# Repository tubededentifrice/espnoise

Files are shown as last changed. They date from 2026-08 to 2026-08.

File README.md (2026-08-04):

# ESPNoise

ESPNoise is a privacy-first noise warning sign for shared workspaces. An ESP32
measures sound energy and lights the word **NOISE** only when the room stays
loud. Short sounds, such as a cough or a dropped object, do not start the
alarm by themselves.

<p align="center">
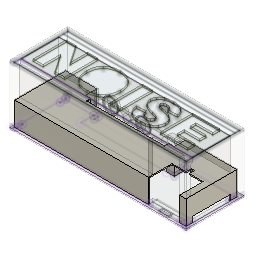
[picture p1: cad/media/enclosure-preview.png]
ESPNoise production enclosure assembly
  
</p>

The repository includes the production enclosure, hardware design, PlatformIO
firmware, and an optional iPhone settings app.

## Main features

- Sustained-noise detection with a rolling decision window
- Green, orange, and red warning levels
- Ten SK6812 RGB plus warm-white pixels behind a printed diffuser
- Optional passive buzzer with a hard power switch
- A 30-minute mute button
- No raw microphone recording or storage
- Wi-Fi off; Bluetooth Low Energy is used only for the optional app
- Firmware targets for a full-size ESP32 and a LOLIN32 Lite

## Production build

The production build uses a full-size ESP32 board and a separate, power-only
USB-C input. A regulated 5 V supply powers the controller and peripherals. The
ESP32 USB-C port stays inside the enclosure as a firmware-service port. No
battery is necessary.

| Item | Production specification |
| --- | --- |
| Controller | Full-size ESP32 development board with USB-C |
| Microphone | ICS-43434 digital I2S microphone on the carrier PCB |
| Display | 10 SK6812 RGB plus warm-white, 32-bit pixels |
| Data buffer | SN74AHCT125PWR, 3.3 V input to 5 V output |
| Sound | 5 V passive electromagnetic buzzer and MMBT3904 driver |
| Controls | Momentary mute button and maintained hard buzzer switch |
| Power | Regulated 5 V, 2 A minimum; 3 A recommended |
| Enclosure | 164 mm × 54 mm × 54.5 mm main case envelope |

See the [bill of materials](docs/bom.md) for the complete part specification.

## 3D-print files

The ready-to-print package and editable source are in
[`cad/production`](cad/production). Start with one of these files:

- [`espnoise.3mf`](cad/production/espnoise.3mf) contains four arranged plates
  and the saved Bambu Studio print profile.
- [`espnoise.f3d`](cad/production/espnoise.f3d) is the editable Autodesk Fusion
  design.
- The individual STL files support other slicers and printers.

The package contains the case, back, reflector, illuminated letters, optional
letter mould, mute-button cap, and buzzer-switch cap.

| Reflector and switch cap | Case, back, and button cap | Letters | Letter mould |
| :---: | :---: | :---: | :---: |
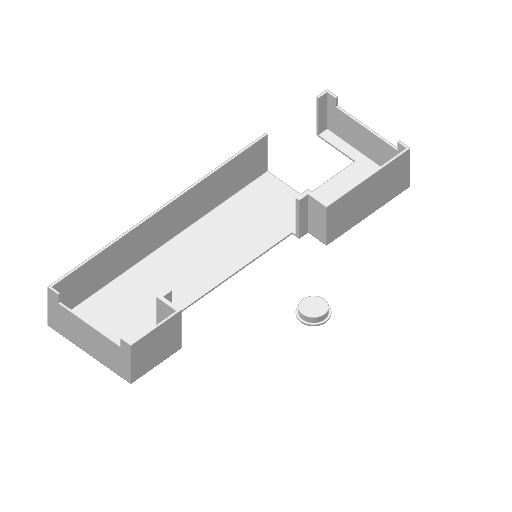
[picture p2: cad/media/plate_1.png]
Reflector print plate
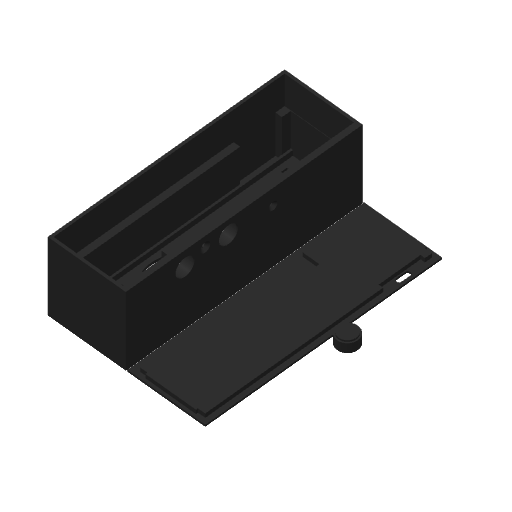
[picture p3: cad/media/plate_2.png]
Case print plate
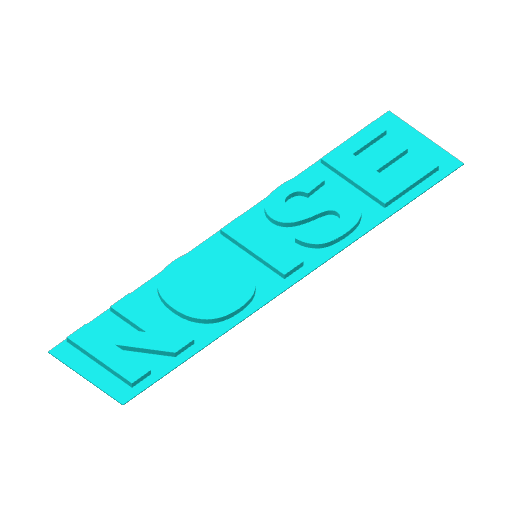
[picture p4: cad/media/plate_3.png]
Letter print plate
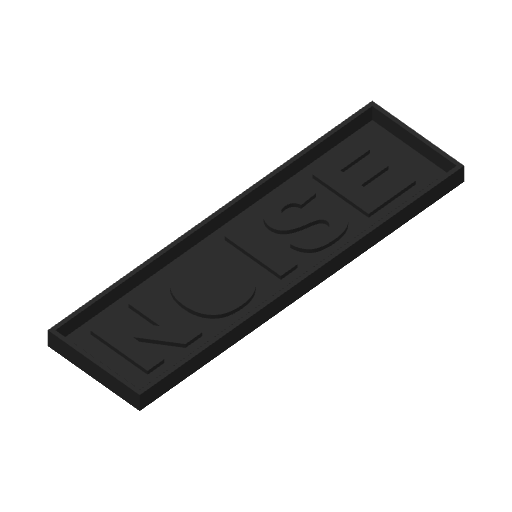
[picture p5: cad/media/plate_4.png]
Letter mould print plate
|  |  |  |  |

The saved profile uses a 0.4 mm nozzle, 0.2 mm layers, two wall loops, 15%
infill, and no supports. Check the profile for your printer and material before
you print. See the [enclosure guide](cad/README.md) for file dimensions,
materials, and assembly notes.

## Wiring

The production wiring uses one common ground. The LED supply does not pass
through the ESP32 board.

```mermaid
flowchart LR
  USB["External power-only USB-C<br>5 V"] --> SPLIT["5 V and GND split"]
  SPLIT --> ESP["ESP32<br>5V/VIN and GND"]
  SPLIT --> FUSE["0.5 A hold fuse"]
  FUSE --> RAIL["5 V peripheral rail"]

  ESP -->|"3V3, GND<br>GPIO26 SCK<br>GPIO25 WS<br>GPIO32 SD"| MIC["ICS-43434<br>L/R to GND"]
  ESP -->|"GPIO18"| AHCT["SN74AHCT125PWR<br>5 V supply"]
  AHCT -->|"330 ohm"| LED["10 × SK6812 RGBW<br>5 V at both ends"]
  RAIL --> AHCT
  RAIL --> LED

  ESP -->|"GPIO23 PWM<br>through 1 kohm"| Q1["MMBT3904 driver"]
  RAIL --> SW["Hard buzzer<br>power switch"]
  SW --> BUZ["Passive magnetic buzzer"]
  BUZ --> Q1

  BTN["Mute button<br>GPIO27 to GND"] --> ESP
```

| Function | ESP32 pin |
| --- | ---: |
| ICS-43434 clock | GPIO26 |
| ICS-43434 word select | GPIO25 |
| ICS-43434 data | GPIO32 |
| SK6812 data through SN74AHCT125PWR | GPIO18 |
| Buzzer PWM through 1 kohm and MMBT3904 | GPIO23 |
| Mute button to GND | GPIO27 |
| Optional battery-boost enable | GPIO13 |

Keep the buzzer switch in the buzzer 5 V wire. Software must not override this
switch. Keep the external two-wire USB-C input separate from the ESP32
firmware-service port. If the power input exposes CC1 and CC2, connect one
5.1 kohm pull-down from each CC pin to GND. Do not connect CC1 to CC2.

See the [complete wiring guide](docs/wiring.md) and the
[interactive prototype-board diagram](docs/prototype-board-wiring.html) before
assembly.

## How detection works

The default rule listens for one second in each ten-second period. It stores
only the maximum sound level from each observation. At least three of the last
six observations must cross a threshold before the alarm starts. Two quiet
checks clear an active alarm.

The default thresholds are in dBFS until you calibrate the unit against a sound
level meter. They are not certified dBA values. Detector values and thresholds
are in [`firmware/include/config.h`](firmware/include/config.h).

## Build guide

1. Check the [bill of materials](docs/bom.md).
2. Print and prepare the [production enclosure](cad/README.md).
3. Follow the [modular assembly stages](docs/modular-build.md).
4. Make the connections in the [wiring guide](docs/wiring.md).
5. Build and upload the [firmware](firmware/README.md).
6. Use the [test and adjustment procedure](docs/detection.md).
7. If necessary, install and configure the optional iPhone app as described in
   [the app and Bluetooth guide](docs/app-and-bluetooth.md).

## Safety and privacy

- Start a new or changed build at 25% LED brightness or less. The production
  USB profile uses its higher limit only after the documented power test.
- Disconnect external 5 V power before you connect the ESP32 service USB port.
- Do not connect a battery to the full-size ESP32 board.
- For the optional battery build, use one protected 3.7 V LiPo pack with the
  correct plug polarity. Do not use loose lithium cells.
- Do not cover the microphone acoustic hole.
- The firmware processes sound levels in memory and does not save raw audio.

## Repository map

```text
cad/                 Production 3D-print files and editable CAD source
docs/                Hardware, wiring, assembly, and test guides
firmware/            PlatformIO firmware for both ESP32 controller options
ios/                 Optional iPhone companion app and Xcode project
```

## License

This project uses the [Functional Source License 1.1, ALv2 Future
License](LICENSE.md). Each release changes to the Apache License 2.0 two years
after that release first becomes available.

FSL is a source-available license before the change date. It permits study,
modification, redistribution, and most uses, but it limits competing commercial
products and services until the change date.

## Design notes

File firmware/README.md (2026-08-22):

# Firmware

## Requirements

- `uv` 0.12 or later, or the PlatformIO IDE extension
- A USB data cable
- The `esp32dev` board definition for the full-size USB-C board
- The `lolin32_lite` board definition for the WEMOS battery board

The repository accepts a third-party dependency only after it is two weeks
old. Reviewed commits from `opendle/opendle-esp32` and
`opendle/opendle-electronics` do not use this cooldown. All dependencies still
need exact versions, hashes, or full Git commits. Git tags and version ranges
are not permitted.

Run the fail-closed policy check before an install or dependency update. The
check verifies the `uv.lock` hashes and dates against PyPI. It reads PlatformIO
and Git commit dates from their services. It also rejects a missing hash, a
version range, a Git tag, or a short Git commit.

```sh
uv sync --locked
uv run --locked opendle-deps check
```

Use `opendle-pio` for each PlatformIO command. The shared tool runs the same
policy check before PlatformIO can install a package.

The same check runs in GitHub Actions. Protect `main` and require the
`Dependency age / check` result so that a change cannot bypass the check. An
urgent security fix that is less than two weeks old needs an explicit policy
change and review. Do not silently remove the cooldown.

## Build

From the repository root, run:

```sh
uv run --locked opendle-pio run
```

This command builds the first USB-powered board. Its ten-pixel power test
passed, so this profile uses 100% LED brightness. The battery board stays an
optional environment and keeps the 25% limit. Build it only when you start the
battery stage:

```sh
uv run --locked opendle-pio run --environment esp32dev
uv run --locked opendle-pio run --environment lolin32_lite
```

At each USB production startup, all ten pixels show green, orange, and red in
quick succession. The buzzer plays one short rising note with each color. The
check takes less than half a second. The detector starts after it finishes.
The hard buzzer switch can disable the notes without disabling the light check.

Use the temporary LED-test environment to show red, green, blue, and
warm-white for one second each after startup:

```sh
uv run --locked opendle-pio run --environment esp32dev_led_test --target upload
```

For a one-pixel bench test, use the fast profile. It listens for 3 seconds in
each 5-second period, keeps a 15-second history, requires at least 50% of the
saved maxima, and uses full LED brightness. It also plays a short buzzer chime
after the LED test:

```sh
uv run --locked opendle-pio run --environment esp32dev_fast_test --target upload
```

Use the calibration profile with the assembled USB-powered product. Send `g`,
`o`, or `r` over the serial monitor. The strip shows the selected solid color
while the firmware measures one 10-second sample. The result is the median of
ten one-second maxima. The buzzer stays off. The calibration profile does not
save raw microphone audio.

```sh
uv run --locked opendle-pio run --environment esp32dev_calibration --target upload
uv run --locked opendle-pio device monitor --baud 115200
```

The tested passive piezo buzzer uses a 2N3904 low-side driver. GPIO23 connects
to its base through 1 kohm. The firmware drives it with 2.4 kHz PWM. The
hard switch stays in the buzzer 5 V wire.

The runtime buzzer-volume value sets the electrical tone amplitude. The
firmware maps this value to the PWM waveform for the passive piezo. Acoustic
loudness is not linear and depends on the buzzer and its enclosure, so adjust
the value after the case is assembled.

## Firmware modules

| Module | Files | Responsibility |
| --- | --- | --- |
| Board profile | `include/board_profile.h` | GPIO pins and optional switched power |
| User settings | `include/config.h` | K, N, X, threshold, colors, and timing |
| Audio input | `include/audio_input.h`, `src/audio_input.cpp` | INMP441 and dBFS frames |
| Detector | `include/noise_detector.h`, `src/noise_detector.cpp` | Observation maximum, rolling history, and X decision |
| Alarm output | `include/alarm_output.h`, `src/alarm_output.cpp` | SK6812, buzzer, and optional power switch |
| Mute control | `include/mute_button.h`, `src/mute_button.cpp`, `include/mute_state.h`, `src/mute_state.cpp` | Button filtering, mute timer, double-press control, and Bluetooth hold detection |
| BLE service | `include/ble_service.h`, `src/ble_service.cpp` | Encrypted settings writes, readback, and status |
| Settings packet | `include/config_packet.h`, `src/config_packet.cpp` | 32-byte packet, limits, and fingerprint |
| Device name | `include/device_name.h`, `src/device_name.cpp` | 20-byte UTF-8 name packet and validation |
| Settings storage | `include/settings_storage.h`, `src/settings_storage.cpp` | Valid settings and device name in NVS |
| Scheduler | `src/main.cpp` | Sample, wait, alarm, mute, and safe settings apply states |

The `esp32dev` environment uses permanent USB peripheral power and the tested
100% LED brightness. The `lolin32_lite` environment keeps the 25% brightness
limit and adds
`ESPNOISE_SWITCHED_PERIPHERAL_POWER=1`. Detection code does not change between
the two power systems.

## Upload

The full-size board was found at `/dev/cu.usbserial-0001` during the first
inspection. The path can change after a reconnect.

```sh
uv run --locked opendle-pio run --environment esp32dev --target upload --upload-port /dev/cu.usbserial-0001
uv run --locked opendle-pio device monitor --port /dev/cu.usbserial-0001 --baud 115200
```

For the WEMOS, connect the external USB-C panel cable to a computer. Then find
its port with `uv run --locked opendle-pio device list` and use the
`lolin32_lite` environment.

Do not upload firmware until the user asks for an upload. A build does not
change a connected board.

## Runtime settings

`include/config.h` contains the compiled defaults and limits. A bonded BLE
client can change analytics collection, LED brightness, buzzer volume, three
thresholds, K, N, the decision window, X, and mute time. The firmware validates
the complete 32-byte packet before it applies a change. It applies the related
values after an observation ends. It then clears the detector history and
alarm state.

When analytics collection changes to off, the device erases its saved
analytics history and stops collection. It does not send analytics while this
setting is off.

The firmware saves a valid packet in NVS only when the complete packet changes.
Thus, a reconnect with the same revision does not make another flash write. A
bad saved record does not start. The firmware uses the compiled defaults
instead. The default device name is `ESPNoise-Device XXXX`, where `XXXX` is
the chip suffix. A synchronized custom suffix replaces `Device XXXX`. The
firmware saves it in a separate NVS record and keeps the `ESPNoise-` prefix.
Fast advertising lasts two minutes. A device with no saved bond keeps first
pairing available. After the first bond succeeds, new-phone pairing lasts two
minutes after startup. Slow connectable advertising continues after this time
for a bonded phone. Hold the mute button for two seconds to disable the complete
Bluetooth controller or to enable it again. The saved state stays active after
a restart. A Bluetooth-blue two-second light change confirms each change. Wi-Fi stays
off.

The encrypted 20-byte status notification sends the current observation
maximum and the saved Green, Orange, and Red threshold counts. Live status is
limited to four measurement notifications each second. A control state change
can send an immediate notification. It sends scalar levels only. It does not
send or save raw microphone audio.

The main compiled values are:

- `kGreenThresholdDbfsX10`: alarm trigger sound set point in signed tenths
  of dBFS
- `kOrangeThresholdDbfsX10` and `kRedThresholdDbfsX10`: louder sound bands
- `kSampleDurationMs`: observation time K
- `kSamplePeriodMs`: observation period N
- `kDecisionWindowMs`: rolling history time
- `kTriggerSampleRatio`: saved maxima ratio X
- `kHistorySampleCount` and `kMinimumHistorySamples`: history requirements
- `kAlarmActiveSampleDurationMs` and `kAlarmOutputWindowMs`: active-alarm
  observation and output timing
- `kBuzzerSettleMs`: silent time between a buzzer pattern and microphone start
- `kGreenStyle`, `kOrangeStyle`, and `kRedStyle`: colors, blink rates, and
  buzzer patterns
- `kLedCount`: number of pixels in the data chain
- `kLedBrightnessMaximum`: board power and brightness limit
- `kPeripheralPowerEnablePin`: battery-build boost control
- `kBuzzerEnabled` and `kBuzzerVolumePercent`: buzzer output
- `kMicrophoneWarmupMs`: ignored microphone settling time after each wake

The firmware is set for 10 SK6812 RGB plus warm-white pixels with the `GRBW`
data order. Some sellers call these pixels `RGBWW`. If a one-pixel test gives
wrong colors, change `NEO_GRBW` in `src/alarm_output.cpp` to the order for the
strip.

Change GPIO pins in `include/board_profile.h`. If you change a pin, also change
`../docs/wiring.md`.

## Serial output

The firmware prints the current and maximum levels during an observation:

```text
level=-53.2 dBFS max=-41.7 dBFS frames=63 mute=off
```

It prints the saved-history count and green, orange, and red observation
percentages after each observation. One high observation does not show a
warning or change the alarm to a higher level. The complete decision history
controls the alarm. The firmware keeps the normal observation interval and
Bluetooth history active during mute. A second mute-button press within 750 ms
ends mute. A later single press restarts the complete mute period. The firmware
does not use application light sleep while BLE is active. This keeps
advertising and connected control available. The NimBLE controller can use its
own modem sleep. The battery profile also turns off the 5 V boost when the
alarm is off.

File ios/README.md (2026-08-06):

# ESPNoise iOS companion

ESPNoise is an iOS 18 or later SwiftUI app. It sends settings to any number of authorized ESPNoise devices through Bluetooth LE.

## Build

Open `ESPNoise.xcodeproj` in Xcode. Select the shared `ESPNoise` scheme and an iPhone with iOS 18 or later. The project keeps local development team `4HX6DP68N3` for a user-authorized phone installation. Change the team only if your Apple account requires a different team.

For an unsigned check, run:

```sh
xcodebuild -project ESPNoise.xcodeproj -scheme ESPNoise \
  -destination 'generic/platform=iOS' CODE_SIGNING_ALLOWED=NO build
```

Use the same command with `build-for-testing` to compile the XCTest target.

## Install and pair

1. Build and install the app on a physical iPhone.
2. Turn on the ESPNoise device and Bluetooth on the iPhone.
3. Open ESPNoise and select **Add Device**.
4. Select a device with a Bluetooth name that starts with `ESPNoise-`.
5. Keep the device near the phone until the app shows **Synchronized**.

If setup reports that it cannot add the accessory, keep the device powered,
restart it, and try **Add Device** again. A device with no completed bond keeps
first pairing available.

Each device page has a synchronized custom name and optional device values.
The custom name is saved on the ESP32 and is available to another phone. A
normal firmware upload keeps it. The hardware-name form `Device XXXX` is
reserved. Sampling values K, N, decision window, and X
are global only. The phone sends its complete effective settings after each
reconnect. Offline settings stay pending.

Noise analytics collection is on by default. The Global Settings page can turn
it off for all devices. Each device can override the global value. A device
with collection off does not collect or save new summaries. It erases its
saved summaries when the setting changes to off.

The Global Settings page saves each valid change on the phone immediately. It
then tries to send the newest complete settings to each connected device. The
Reset Global Values action saves the compiled defaults immediately. Device
overrides and names stay unchanged.

Green, orange, and red threshold sliders use the same quieter-to-louder scale.
The displayed scale is a positive relative level from 0 through 120. It is not
calibrated dB SPL. The app keeps these thresholds in color order while the
user moves a slider.

The top of each device page graphs live observation maxima against the three
thresholds. It also shows how many saved observations reached each threshold.
The Global Settings page shows one live chart for each device that is in range.
This short graph history stays in app memory only. The phone does not receive
raw microphone audio.

The Noise Analytics page reads 15-minute summaries from each device. A device
keeps at most 72 hours. The phone keeps at most 30 days for each device. The
page can show one device, a selected group, or all devices. It shows average
and peak relative levels, state time, time trends, device comparisons, and a
weekday and hour heatmap. The phone sends UTC time when it requests the
summaries. The page requests data when it opens and has a refresh control. The
app can also read the old analytics packet until the device has version 2
firmware. The summaries do not contain audio.

Hold the device mute button for two seconds to disable or enable the complete
Bluetooth controller. The device saves this state after a restart. The app
cannot synchronize while Bluetooth is off.

## Sync rules

Phone settings always win. Global settings, device overrides, and valid device
names save on the phone as they change. For each device, the app permits one
active settings write and one pending request for the newest complete settings.
Additional changes replace that pending request. A write response does not
complete a sync. The app completes a sync only when the device reports the
desired revision and the matching FNV-1a fingerprint. The app keeps stale,
delayed, duplicate, or incorrect reports separate for each device. iOS controls
connection and background timing, so the app does not promise a fixed update
time.

## Privacy

The app uses AccessorySetupKit and Core Bluetooth. It does not use Internet
access, location, accounts, or an external analytics service. Aggregated noise
history stays on the devices and the phone. It does not collect or save raw
microphone audio. Logs do not include device settings or device identifiers.

## Physical-device gates

Complete these checks before release:

- Confirm AccessorySetupKit pairing with production firmware.
- Confirm reconnect and state restoration after the app moves to the background.
- Confirm that an offline edit stays pending and syncs after reconnect.
- Confirm status notifications, readback, wrong fingerprints, stale revisions, and delayed reports.
- Confirm operation with multiple authorized devices at the same time.
- Confirm history recovery after a device stays out of range for one hour.
- Confirm analytics selection and charts with at least three devices.
- Confirm that the battery build never drives the LEDs above its 25% board
  limit. The USB build has a completed 100% power test.
- Confirm that a force-quit app does not claim background operation.

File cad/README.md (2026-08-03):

# Production enclosure

This directory contains the release enclosure for the USB-powered ESPNoise
build. The main case envelope is 164 mm by 54 mm by 54.5 mm.

ESPNoise enclosure assembly

## Choose a file

- Open [`production/espnoise.3mf`](production/espnoise.3mf) in Bambu Studio to
  use the arranged plates and saved print profile.
- Open [`production/espnoise.f3d`](production/espnoise.f3d) in Autodesk Fusion
  to change the design.
- Import the individual STL files into another slicer when you do not use the
  3MF package.

Do not scale the models. The STL coordinate origins are assembly coordinates,
so an individual part can open away from the slicer origin. Use the slicer's
place-on-bed and arrange functions.

## Included parts

The dimensions below are axis-aligned STL bounds in millimetres.

| File | Purpose | Size, X × Y × Z |
| --- | --- | ---: |
| [`case.stl`](production/case.stl) | Main enclosure | 164.0 × 54.0 × 54.5 |
| [`back.stl`](production/back.stl) | Rear cover | 164.0 × 54.0 × 4.4 |
| [`reflector.stl`](production/reflector.stl) | LED light divider | 159.3 × 47.3 × 22.0 |
| [`letters.stl`](production/letters.stl) | Illuminated NOISE face | 159.0 × 35.0 × 2.4 |
| [`letters-mould.stl`](production/letters-mould.stl) | Optional letter mould | 173.0 × 49.0 × 8.6 |
| [`button.stl`](production/button.stl) | Momentary-button cap | 14.3 × 8.0 × 14.3 |
| [`toggle-button.stl`](production/toggle-button.stl) | Buzzer-switch cap | 14.3 × 4.0 × 14.3 |

## Saved print profile

The 3MF package was saved from Bambu Studio 2.7 for a Bambu Lab X1 Carbon.
Its main settings are:

| Setting | Saved value |
| --- | --- |
| Nozzle | 0.4 mm |
| Layer height | 0.2 mm |
| Wall loops | 2 |
| Sparse infill | 15% |
| Supports | Off |
| Bed adhesion | Automatic brim |

The saved material assignments are cyan PETG for the letters, white PLA for
the reflector and switch cap, and black PLA for the case, back, button cap, and
letter mould. These colors help the sign control stray light. Equivalent colors
and materials can be used after a small fit and light test.

Check temperatures, cooling, bed adhesion, and dimensional compensation for
your printer. Print the small button parts first. Confirm their fit before you
start the case.

## Assembly notes

1. Remove all brim material and clean the button openings.
2. Test-fit the button and switch caps. They must move freely.
3. Put the reflector behind the letter face.
4. Align two SK6812 pixels behind each letter.
5. Keep the microphone acoustic hole clear and away from the buzzer.
6. Install the electronics with removable connectors.
7. Fit the back only after the wiring and power tests pass.

Do not put pressure, a screw, a sharp edge, or a hot part against a LiPo pack.
The production enclosure is for the USB-powered build. A battery version needs
a separate fit, clearance, and temperature review.

## Design compatibility

Low-cost ESP32 boards with the same product name can have different board,
connector, and mounting dimensions. Compare your parts with the Fusion model
before a long print. If you change a component, keep the changed hardware
assumption in this file and update the related model.

[`production/SHA256SUMS`](production/SHA256SUMS) contains checksums for all
release assets.

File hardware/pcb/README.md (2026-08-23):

# ESPNoise carrier PCB

For the nominal 70 mm by 50 mm home-milled blank, use
[`cnc/README.md`](cnc/README.md). The Cubiko files contain one unit. Run them
twice with a 180-degree blank rotation between the two runs. The prototype uses
larger through-hole parts, individual wire terminals, registration holes,
Gerber files, and Cubiko G-code.
The Rev B factory board below stays separate.

This directory contains the carrier PCB for the USB-powered ESPNoise build.
The ESP32 stays on a removable cable. The PCB contains the controls, digital
microphone, buzzer, LED data buffer, buzzer driver, fuse, and keyed connectors.

The board is 80 mm by 20 mm. Its nominal stack is two copper layers, 1.6 mm
FR-4, 1 oz copper, lead-free HASL, and a green solder mask.

## Interface summary

The controller, LED, and USB-C power connectors are JST PH vertical headers on
the lower face. A cable enters each connector in the direction away from that
face. The two switches, microphone opening, and buzzer are on the 10 mm board
centerline and face the case top.

MIC1 is on the lower face because it is a bottom-port microphone. A 0.5 mm
non-plated hole carries sound from the case top to the microphone port. Do not
cover this hole with glue, foam, or a label.

The controller interface uses signal names. It does not depend on the physical
size of the ESP32 board. Make one adapter cable for the selected controller.
The current `esp32dev` pin map is in `docs/wiring.md`. An ESP32-C3 needs a
separate firmware target and a different adapter cable before use.

## Factory order files

The `jlcpcb` directory contains these order files:

- `espnoise-carrier-gerbers.zip`: PCB fabrication data.
- `espnoise-carrier-bom.csv`: component list for assembly.
- `espnoise-carrier-cpl.csv`: component placement data.
- `espnoise-carrier-top.svg` and `espnoise-carrier-bottom.svg`: assembly views.

Upload the Gerber ZIP in the JLCPCB PCB order page. Enable PCB assembly, and
then upload the BOM and CPL files. Check every mapped part and orientation in
the assembly preview. In particular, check C2 and D1 polarity, MIC1 pin 1, pin
1 of all JST connectors, BZ1 polarity, and the six pins on each switch.

JLCPCB stock can change. Do not submit the order if the site replaces a part
without a new electrical and footprint check.

## Regeneration

Run `uv run --locked opendle-kicad export --config opendle-tools.toml` from the
repository root. The pinned shared tool needs KiCad 10 and its Python `pcbnew`
module. It regenerates the board, Gerbers, drill files, BOM, CPL, assembly
views, and hash manifest.

The generator is the controlled source for the board layout. Do not edit the
generated board without the same change in `generate_board.py`.

Use these documents with the order package:

- `electrical-design.md` gives the circuit and selected factory parts.
- `controller-adapters.md` gives all cable pin orders.
- `order-guide.md` gives the JLCPCB upload and preview checks.

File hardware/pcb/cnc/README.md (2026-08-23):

# ESPNoise Rev C CNC unit

This directory contains a two-copper-face PCB for the Genmitsu Cubiko. One
nominal 70 mm by 50 mm FR-4 blank can make two units. The machine files contain
one unit only. Run each unit file, rotate the complete blank by 180 degrees in
its plane, set the work origin again, and run the same file a second time.

This method references each unit from an outside factory edge. An error in the
blank height stays in the center area. The file does not contain a second,
rotated unit. The rear-copper file still contains the X mirror that is required
for a left-to-right copper-face flip.

The mute button, hard buzzer switch, microphone acoustic center, and buzzer
center are on one line at local Y = 12.25 mm. Their local X positions are
6.5 mm, 17.5 mm, 35.5 mm, and 60.5 mm. All other component bodies and all wire
terminals are on the internal face.

Unit user face

Unit internal face

The electrical schematic is in `espnoise-cnc-schematic.svg`. The exact pin
connections are in `pinout.md` and `espnoise-cnc-netlist.csv`. The editable
unit PCB is `espnoise-cnc.kicad_pcb`. The generator is the controlled layout
source.

This layout uses the measured buzzer dimensions, the confirmed microphone pin
pattern, and a centered microphone acoustic hole. The microphone body diameter
is approximately 13 mm. Print `espnoise-component-fit-check.svg` at 100% scale
and put the real parts on the drawing before you mill the complete blank.

## Important design limits

- Nominal raw blank: 70 mm by 50 mm
- Unit job area: 70 mm by 24.5 mm
- Supported assumed minimum blank: 69 mm by 49 mm
- Layout shift: 0.50 mm toward the left edge
- Copper faces: two
- Minimum track width: 1.00 mm
- Minimum checked copper clearance: 0.40 mm
- Power track width: 1.30 mm
- Milled isolation width: 0.40 mm
- Microphone pads: 2.00 mm copper with 1.00 mm holes
- Buzzer pads: 2.00 mm copper with 0.80 mm holes
- Mounting hole: one 2.0 mm hole at X = 34.5 mm for each unit run
- Wire vias: 0.8 mm holes with 1.7 mm copper pads
- No plated holes and no solder mask
- 1.2 mm holes for the individual wire terminals
- No insulated link wires
- No LED logic-level IC

The board uses direct insulated wires instead of cable headers. The exact
signal for each pad is in `pinout.md`, the netlist, the schematic, and the
internal-face SVG.

| Pad group | Connection |
| --- | --- |
| PWR1-1 / PWR1-2 | External +5 V / GND |
| J_ESP32-1 through J_ESP32-9 | ESP32 5 V, GND, 3.3 V, and six GPIO wires |
| J_LED-1 / J_LED-2 / J_LED-3 | LED +5 V / DIN / GND |

The LED data path is a direct trace from ESP32 GPIO18 to J_LED-2. This matches
the tested prototype. It is not a guaranteed 5 V logic interface. Keep the
wire short. If the installed strip is not reliable, add an external 5 V logic
buffer near the strip.

The buzzer driver parts stay on the board. The specified magnetic 5 V buzzer
must not connect directly to an ESP32 GPIO. SW2 stays as a hard switch in the
buzzer power wire and can remove all buzzer power.

MIC1 is the round MH-ET LIVE INMP441 module with two rows of three pins. With
the printed-label and acoustic-hole face toward the case top, and with the
notch at the local top edge, the top row is `GND`, `VDD`, `SD`. The bottom row
is `L/R`, `WS`, `SCK`. `L/R` connects to GND. This is the same view as the
supplied product image.

BZ1 is a 12 mm passive two-pin through-hole buzzer. Its lead pitch is 6.5 mm,
and each lead is 0.5 mm. Pad 1 is positive. Pad 2 is negative and connects to
the transistor collector.

## Generate the files

Install `pcb2gcode`. On macOS, use this command:

```sh
brew install pcb2gcode
```

Then run this command from the repository root:

```sh
uv run --locked opendle-cnc build --config opendle-tools.toml
```

The script does these tasks:

1. It generates one unit PCB.
2. It checks the board limits, body overlap, copper width, and clearance.
3. It makes one user-face isolation job and one mirrored internal-face job.
4. It makes one unit G-code file for each drill size.
5. It checks all X, Y, and Z limits and writes SHA-256 checksums.

The ready files are in `machine`. Do not run them until the coupon and the
preflight checks in `cubiko-guide.md` pass.

## Source files

| File | Purpose |
| --- | --- |
| `generate_cnc_board.py` | Unit source, router, and checks |
| `espnoise-cnc.kicad_pcb` | Editable and reviewable 70 mm by 24.5 mm unit |
| `espnoise-cnc-user.svg` | Single-unit user-face check view |
| `espnoise-cnc-internal.svg` | Single-unit internal-face check view |
| `espnoise-cnc-schematic.svg` | Electrical schematic |
| `pinout.md` | Complete pad and connector pin map |
| `espnoise-component-fit-check.svg` | 1:1 physical part fit check |
| `espnoise-cnc-netlist.csv` | Exact pin-to-net table |
| `espnoise-cnc-bom.csv` | Parts and face assignment for one unit |
| `millproject` | Single-unit isolation values |
| `millproject-coupon` | Coupon isolation values |
| `opendle-tools.toml` | Project paths, process values, and machine limits |
| `opendle-electronics` | Pinned shared CAM, G-code checks, and manifests |

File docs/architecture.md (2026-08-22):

# System design

## Main signal path

```mermaid
flowchart LR
  MIC["INMP441 microphone"] -->|"16 kHz I2S"| ESP["ESP32"]
  ESP -->|"GPIO through 74AHCT125"| LED["10 SK6812 RGBW pixels"]
  ESP -->|"GPIO23 through 1 kohm"| DRIVER["2N3904 driver"]
  SW["Hard buzzer switch"] -->|"Switched 5 V"| BUZ["Passive piezo buzzer"]
  BUZ --> DRIVER
  B30["30-minute mute button"] --> ESP
```

The ESP32 reads audio samples but does not keep them. It calculates the sound
energy and discards each sample block.

## Module boundaries

```mermaid
flowchart LR
  POWER["Replaceable 5 V power module"] --> BOARD["Board profile"]
  MIC["Audio input module"] --> DETECT["Noise detector module"]
  DETECT --> STATE["Scheduler and state module"]
  BUTTON["Mute-control module"] --> STATE
  PHONE["iPhone settings app"] -->|"Bluetooth LE"| BLE["BLE settings module"]
  BLE --> STORE["Settings storage module"]
  STORE --> STATE
  STATE --> OUTPUT["Alarm-output module"]
  BOARD --> MIC
  BOARD --> BUTTON
  BOARD --> OUTPUT
```

The first power module is the ESP32 USB-C input and its 5 V header. A later
battery module can replace it. The audio and detector modules do not depend on
the power source.

## State flow

```mermaid
stateDiagram-v2
  [*] --> Observation
  Observation --> History: Save one-second maximum
  History --> AlarmOutput: At least X percent of the last six maxima cross a threshold
  History --> Wait: No threshold has at least X percent
  Wait --> Observation: N-second period starts
  AlarmOutput --> Recheck: 250 ms output ends
  Recheck --> History: Save maximum and remove oldest value
  state Muted {
    [*] --> MutedObservation
    MutedObservation --> MutedWait: Save maximum and update history
    MutedWait --> MutedObservation: N-second period starts
  }
  Wait --> Muted: Mute button is pressed
  AlarmOutput --> Muted: Mute button is pressed
  Recheck --> Muted: Mute button is pressed
  Observation --> Muted: Mute button is pressed; observation continues
  Muted --> AlarmOutput: Mute ends and history crosses a threshold
  Muted --> Wait: Mute ends and history is below the thresholds
```

Mute gates the alarm outputs. It does not stop the microphone observation
schedule or clear the rolling history. A second button press within 750 ms
ends mute.

## Alarm result

Separate dBFS thresholds control the alarm level. At least three of the six
saved one-second maxima must cross a threshold to start its level.

| Level | Default threshold | Light | Buzzer |
| --- | ---: | --- | --- |
| Green | -55 dBFS | Slow green blink | Silent |
| Orange | -48 dBFS | Medium orange blink | Two warning notes |
| Red | -42 dBFS | Fast red blink | Three warning notes |

During an active alarm, each one-second maximum enters the rolling history.
The highest threshold with at least three values sets the output color. The
alarm stops when fewer than three values reach Green.

The brightness limit applies after the color is set. The tested USB-powered
`esp32dev` profile uses 100%. The untested battery profile stays at 25%.

## Design choices

### INMP441 microphone

The INMP441 is suitable for the first build. Its digital output avoids ESP32
ADC noise. Its stable response helps with repeatable tests. It uses about
1.4 mA. A cheap sound switch module such as a KY-038 is not a good replacement.
Its set point can change with supply noise, temperature, and its adjustment
control.

For a lower-cost production version, test an analog MAX4466 microphone module.
It needs a new calibration and an ADC filter. Do not change the first
prototype until the INMP441 result is known.

### Light output

The LEDs do not draw letters. The printed front panel contains the word
`NOISE`. Ten pixels light a white diffuser behind the cut-out letters. Two
pixels behind each letter give an even light level. Ten pixels use about
167 mm of a 60-pixel/m strip.

### Phone control

The iPhone app uses Bluetooth Low Energy to manage the main settings. It keeps
one global profile and optional device overrides. The phone is the settings
source. Each ESP32 validates and saves one complete effective profile.

The app can change brightness, buzzer volume, three thresholds, mute duration,
analytics collection, K, N, decision-window time, and X. Analytics collection,
brightness, buzzer volume, thresholds, and mute duration can have a device
override. K, N, decision-window time, and X are global only. See
[iPhone app and Bluetooth settings](app-and-bluetooth.md).

Bluetooth stays on for device discovery and reconnect unless the user holds
the mute button for two seconds. This hold disables the complete Bluetooth
controller. The device saves this state. The same hold enables Bluetooth.
Wi-Fi stays off. Radio use can reduce battery time and needs a battery test.

## Source data

- [WEMOS D32 battery and charge data](https://www.wemos.cc/en/latest/d32/d32.html)
- [ESP32-DevKitC documentation](https://docs.espressif.com/projects/esp-dev-kits/en/latest/esp32/esp32-devkitc/user_guide.html)
- [ESP32 series data sheet](https://documentation.espressif.com/esp32_datasheet_en.html)
- [INMP441 data sheet](https://invensense.tdk.com/wp-content/uploads/2015/02/INMP441.pdf)
- [SK6812 RGBW data sheet](https://cdn-shop.adafruit.com/product-files/2757/p2757_SK6812RGBW_REV01.pdf)
- [SN74AHCT125 data sheet](https://www.ti.com/lit/gpn/SN74AHCT125)

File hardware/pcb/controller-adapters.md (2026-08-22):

# Controller adapter cables

The Rev C home-milled board uses JST-XH connectors with the same signal order.
Use `XHP-10`, `XHP-5`, and `XHP-2` cable housings for Rev C. Use contacts that
the JST-XH housing manufacturer approves. Do not force a JST-PH housing into a
JST-XH header.

J2 is a controller-independent signal connector. The carrier PCB does not
contain an ESP32. Use one adapter cable between J2 and the selected development
board.

The cable housing is JST `PHR-10`. Use JST `SPH-002T-P0.5S` crimp terminals or
an approved equivalent. Mark pin 1 before you install the cable.

## J2 signal order

| J2 pin | Signal | Full-size ESP32 adapter | ESP32-C3 SuperMini adapter |
| ---: | --- | --- | --- |
| 1 | `+5V_IN` | `5V` or `VIN` | `5V` |
| 2 | `GND` | `GND` | `GND` |
| 3 | `+3V3` | `3V3` | `3V3` |
| 4 | `MIC_SCK` | GPIO26 | GPIO4 |
| 5 | `MIC_WS` | GPIO25 | GPIO5 |
| 6 | `MIC_SD` | GPIO32 | GPIO6 |
| 7 | `LED_DATA_3V3` | GPIO18 | GPIO7 |
| 8 | `BUZZER_PWM` | GPIO23 | GPIO3 |
| 9 | `MUTE_N` | GPIO27 | GPIO10 |
| 10 | `GND` | `GND` | `GND` |

Use two controller GND pins when the board has them. If the board has only one
convenient GND pin, make the GND split in the adapter cable. Do not omit either
J2 ground wire.

The current firmware supports the full-size ESP32 pin map. It does not yet
include an ESP32-C3 build environment. The C3 column is the reserved adapter
map for a future firmware port. Do not connect a C3 and expect the current
`esp32dev` binary to operate.

Do not connect external 5 V power and the controller service USB port at the
same time. Disconnect J1 before you connect the service USB cable.

## Other PCB connectors

| Connector | Cable housing | Pin order |
| --- | --- | --- |
| J1, power input | JST `PHR-2` | 1 `+5V_IN`, 2 `GND` |
| J3, LED strip | JST `PHR-5` | 1 `+5V` first end, 2 `GND` first end, 3 `DIN`, 4 `+5V` far end, 5 `GND` far end |

J1, J2, and J3 are mounted on the lower PCB face. Their cable entry direction
is away from that face. Thus, the installed cables point down. The microphone
and buzzer are on the PCB and do not use cable connectors.

The J3 cable divides power and ground between the two strip ends. Connect pin
3 only to the first pixel `DIN`. Do not connect it to the far strip end.

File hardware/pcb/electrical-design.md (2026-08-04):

# Electrical design

The carrier is for the USB-powered ESPNoise build. It includes the microphone
and buzzer. It does not include a battery charger, lithium cell, boost
converter, ESP32 module, LED strip, or external USB-C socket.

## Power path

J1 receives 5 V and GND from a power-only USB-C input module. The 5 V line
splits before F1. One branch goes directly to J2 for the removable controller.
The other branch goes through the 0.5 A resettable fuse to the LED buffer, LED
connector, bulk capacitor, and hard buzzer switch.

The external USB-C module must have one 5.1 kohm pull-down from CC1 to GND and
one 5.1 kohm pull-down from CC2 to GND. Do not combine CC1 and CC2. The
controller USB connector remains a separate firmware-service port.

## LED data

U1 is an SN74AHCT125 supplied from the fused 5 V rail. Channel 1 changes the
ESP32 3.3 V data to a 5 V data signal. R1 is the 330 ohm series resistor. C1 is
the 100 nF U1 bypass capacitor. C2 is the 1,000 uF LED rail capacitor.

J3 supplies the SK6812 RGB plus warm-white strip at both ends. The data path is
32-bit RGBW. Keep firmware brightness at 25% or less until power tests show
that a higher value is safe.

## Microphone

MIC1 is a TDK InvenSense ICS-43434 I2S microphone. It uses the same SCK, WS,
and SD interface as the prototype INMP441 module. Its L/R input is connected
to GND. C3 is its 100 nF supply bypass capacitor.

MIC1 is on the lower face and has a bottom acoustic port. Its footprint has a
0.5 mm non-plated hole. This hole faces the case top and is on the same board
centerline as the switches and buzzer.

## Buzzer and controls

SW2 is a DPDT push-push switch. The PCB uses one pole as a hard switch in the
buzzer 5 V wire. The switch data sheet connects pins 1 and 2 when the plunger
is extended. Thus, extended means buzzer enabled. The second pole is not used.

BZ1 is a 5 V passive electromagnetic buzzer. Its 2.4 kHz resonance agrees with
the red alarm tone. Q1 is an MMBT3904 low-side driver. R2 is 1 kohm and limits
the transistor base current. R3 keeps Q1 off while the controller starts or is
disconnected. D1 is the flyback diode for the buzzer coil.

SW1 is the matching momentary switch body. It connects `MUTE_N` to GND when
pressed. The controller supplies the input pull-up.

## Factory components

| Ref | Part | LCSC/JLCPCB ID |
| --- | --- | --- |
| U1 | SN74AHCT125PWR | C36365 |
| Q1 | MMBT3904 | C181119 |
| F1 | 1206L050YR, 0.5 A hold PTC | C163512 |
| C1, C3 | 100 nF, 0603 | C14663 |
| C2 | 1,000 uF, 10 V, 105 degrees C | C5246577 |
| D1 | 1N5819WS flyback diode | C191023 |
| R1 | 330 ohm, 0603 | C23138 |
| R2 | 1 kohm, 0603 | C21190 |
| R3 | 100 kohm, 0603 | C25803 |
| MIC1 | TDK InvenSense ICS-43434 | C5656610 |
| BZ1 | FUET FUET-1370F-05 | C2690507 |
| SW1 | SHOU HAN `7-7 WS`, momentary | C5379890 |
| SW2 | SHOU HAN `7-7 ZS`, latching | C5379891 |
| J1 | JST B2B-PH-SM4-TBT | C265003 |
| J2 | JST B10B-PH-SM4-TBT | C265112 |
| J3 | JST B5B-PH-SM4-TBT | C265086 |

Check the JLCPCB assembly library stock before each order. Do not replace an
AHCT part with an HC part or a generic MOSFET level shifter.

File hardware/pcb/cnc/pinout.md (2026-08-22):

# ESPNoise Rev C pin and part map

This document uses the view from the marked face of each part. The marked face
points toward the top opening of the case. The internal PCB face contains the
wire pads and the buzzer driver parts.

The microphone pin pattern, centered acoustic hole, and buzzer dimensions come
from the prototype parts. The microphone body diameter is approximately
13 mm. Use the 1:1 fit check before you engrave the full panel.

## PWR1: external 5 V power wires

| PCB pad | Connect to | Function |
| --- | --- | --- |
| PWR1-1 | External red wire | +5 V input |
| PWR1-2 | External black wire | GND |

The external power input must stay separate from the ESP32 firmware-service
USB port. Do not power both ports at the same time.

## J_ESP32: individual wires to the ESP32

These are individual solder pads. `J_ESP32` is their electrical group name.
It is not a plug housing.

| PCB pad | ESP32 connection | Signal destination |
| --- | --- | --- |
| J_ESP32-1 | VIN or 5V | +5 V input, before F1 |
| J_ESP32-2 | GND | Common GND |
| J_ESP32-3 | 3V3 | MIC1-2 VDD |
| J_ESP32-4 | GPIO26 | MIC1-6 SCK |
| J_ESP32-5 | GPIO25 | MIC1-5 WS |
| J_ESP32-6 | GPIO32 | MIC1-3 SD |
| J_ESP32-7 | GPIO18 | J_LED-2 DIN |
| J_ESP32-8 | GPIO23 | R2, then Q1 base |
| J_ESP32-9 | GPIO27 | SW1-5 MUTE_N |

## J_LED: individual wires to the LED strip

| PCB pad | LED strip connection |
| --- | --- |
| J_LED-1 | +5 V after F1 |
| J_LED-2 | DIN, direct from ESP32 GPIO18 |
| J_LED-3 | GND |

The direct 3.3 V data signal matches the tested short-wire prototype. A 5 V
SK6812 data input does not have a guaranteed 3.3 V margin. If the strip is not
stable, install an external 5 V logic buffer close to the strip.

## MIC1: MH-ET LIVE INMP441 module

Install the module with its printed-label and acoustic-hole face toward the
case top. The pin diagram below is the view from that face. Put the edge notch
at the local top edge of the PCB, as shown in the supplied product image.

```text
                  LOCAL TOP EDGE / NOTCH

                  1 GND   2 VDD   3 SD

                  4 L/R   5 WS    6 SCK

                  LOCAL BOTTOM EDGE
```

MIC1-4 `L/R` connects to GND. The firmware reads both I2S slots, but this
connection gives the module a defined channel.

The module already contains its local microphone support parts. Do not add a
second microphone resistor or capacitor.

## BZ1: two-pin buzzer

Use the top sound-port view:

```text
        BZ1-2  -             +  BZ1-1
     Q1 collector         switched +5 V
```

The PCB uses two drilled holes. It does not use side SMD pads. Confirm the
positive mark on the real buzzer before solder.

## Switch contacts

| Switch | Used pads | Connection |
| --- | --- | --- |
| SW1 MUTE | 5 and 6 | GPIO27/MUTE_N to GND when pressed |
| SW2 BUZZER ENABLE | 4 and 5 | +5 V peripheral rail to BZ1-1 when enabled |

Check these contact pairs with a multimeter before solder. Seller switch
contact numbering can differ.

## Support parts that remain

| Part | Purpose |
| --- | --- |
| F1, 0.5 A PTC | Limits fault current in the LED and buzzer branch |
| Q1, 2N3904 | Keeps buzzer current out of ESP32 GPIO23 |
| R2, 1 kohm | Limits Q1 base current |
| R3, 100 kohm | Keeps Q1 off while GPIO23 floats during reset |
| D1, 1N5819 | Clamps the turn-off pulse from a magnetic buzzer coil |

The PCB has no LED resistor, no bulk capacitor, no LED level shifter, and no
extra microphone passives.

## Physical values

| Value | PCB value | Source |
| --- | ---: | ---: |
| MIC1 round body diameter | 13.00 mm | Approximate |
| MIC1 pin pitch inside each row | 2.54 mm | Confirmed on prototype board |
| MIC1 distance between rows | 7.62 mm | Confirmed: two empty 2.54 mm rows between occupied rows |
| MIC1 acoustic-hole X offset from body center | 0.00 mm | Confirmed centered |
| MIC1 acoustic-hole Y offset from body center | 0.00 mm | Confirmed centered |
| BZ1 body diameter | 12.00 mm | Measured |
| BZ1 lead pitch | 6.50 mm | Measured |
| BZ1 lead diameter | 0.50 mm | Measured; PCB drill is 0.80 mm |

The centered microphone acoustic hole is on the switch and buzzer centerline.

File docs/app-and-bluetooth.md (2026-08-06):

# iPhone app and Bluetooth settings

The ESPNoise iPhone app manages one or more ESPNoise devices. The app uses
Bluetooth Low Energy. It does not need Wi-Fi, an Internet service, an account,
location data, or an external analytics service.

The firmware does not send or save raw microphone audio. It sends live status
and private 15-minute noise summaries.

## Settings model

The app keeps one global profile. Each device uses this profile by default.
A device can override these values:

- Noise analytics collection
- LED brightness
- Buzzer volume
- Green, orange, and red positive relative-level thresholds
- Mute-button duration

Observation time K, observation period N, decision-window time, and sample
ratio X are global values. A device cannot override them.

Each device page shows the inherited or overridden state of each applicable
value. A reset action removes the override. It does not copy the current
global value into a new override.

The app saves a valid settings change automatically after a short wait.
This prevents a slider movement from sending one Bluetooth write for each
intermediate value. When the user leaves a settings page, the app saves the
latest valid value without a delay. The Global Settings reset action saves the
compiled defaults. It does not remove device overrides or device names.

A custom device name is saved on the phone and in ESP32 nonvolatile storage.
It uses a separate synchronization state from the measurement settings. A
new phone adopts the name that it reads from the device. A normal firmware
upload keeps the saved name. If a full flash erase removes the name, a phone
that previously confirmed the name restores it. The name can use no more
than 18 UTF-8 bytes. Names in the form `Device XXXX`, where `XXXX` is four
hexadecimal digits, are reserved for the hardware default name.

The firmware keeps thresholds as signed dBFS values. The app presents them as
a positive relative level from 0 through 120. It adds 120 to the dBFS value,
so louder sound has a larger displayed number. This value is not calibrated
dB SPL.

## Synchronization rule

The phone is the settings source. A complete effective profile is sent after
each device connection. Thus, these events start synchronization:

- The device starts while the phone is in range.
- The device returns to range.
- The app starts and reconnects.
- The user selects **Retry Synchronization**.
- A saved phone setting changes while the device is connected.

If a setting changes while a device is out of range, the app marks that
device as pending. The device continues to use its last valid saved profile.
The app sends the pending profile after the next connection.

The app does not report success after the Bluetooth write alone. The device
must validate, save, and apply the profile. It then returns the phone revision
and a settings fingerprint. The app records the synchronization time only
when both values match its desired profile.

Do not let two phones automatically manage the same device. The phone that
reconnects last can replace the settings from the other phone. A phone does
not write a device name only because it connects. It adopts a different valid
name from the device unless it has a pending user edit.

## Device page and fleet status

The home page shows these important values for each device:

- Device name
- In range or out of range
- Current alarm state when the value is fresh
- Synced, pending, or error state
- Time of the last successful settings synchronization

Each device has a separate page for its live measurement graph, rolling alarm
counts, overrides, effective values, manual synchronization, and removal. The
graph uses the same positive 0-through-120 scale as the threshold controls.
It keeps up to five minutes of observation maxima in app memory. The alarm uses
the highest color whose rolling count reaches the required value.

The app has no configured device-count limit. The practical count of active
Bluetooth connections depends on iOS, the radio environment, and the distance
to each device.

## Noise analytics

The global profile has a noise analytics collection switch. Each device can
override this switch. When the effective switch is off, the device does not
make, save, or send noise summaries. It erases the summaries that it saved
before the switch changed to off. The app does not request summaries from that
device. Summaries that the phone received before the change stay on the phone.

Each device makes one highly aggregated summary for each 15-minute period.
Each summary has these values:

- Time in the green, orange, and red states
- Time in the quiet state, calculated from the period length
- Time-weighted average relative noise level
- Peak relative noise level

The device keeps at most 72 hours of summaries in a ring. It saves the ring to
flash once each hour. It saves the next record sequence after each completed
summary. A power loss can remove the newest unsaved summaries, but it does not
cause an old sequence to be used again.

The app requests only records that are newer than its last completed record.
It also requests the current partial period. The phone keeps at most 30 days
for each device. Each request sends the current UTC time to the device. The
device uses this value to time the current record and any records made since
the current boot. Each saved record keeps its UTC start time. The ESP32 has no
hardware real-time clock, so it cannot time records across a power loss until
the phone connects again. A power loss or a long time out of range can cause a
gap. The app does not estimate missing data.

The app sends a new request when the analytics page opens and when the user
selects refresh. This permits recovery if the first request for a Bluetooth
connection does not complete. The app can read the old version 1 analytics
packets until the device has version 2 firmware. Old packets do not contain a
UTC time, so the app assigns their dates when they arrive.

The analytics page can select one device, a group, or all devices. It shows
average and peak levels, warning-state time, trends, device comparisons, a
weekday and hour heatmap, and device-hours of available data. The device
comparison shows the 12 devices with the most warning-state time. All selected
devices still contribute to the other fleet values. This keeps the page useful
for an office with up to 100 devices.

## Setting limits

The app checks a profile before it sends it. The device checks it again before
it saves or applies it. The device is the final safety control.

- Brightness and buzzer volume are from 0% through 100%.
- The battery-build brightness output cannot be more than 25% until a power
  test approves a higher value.
- Green must be lower than orange, and orange must be lower than red.
- K must be greater than zero and cannot be greater than N.
- The decision window must be a multiple of N.
- X cannot permit one observation to start an alarm.
- A settings change clears old detector history. Old observations do not use
  the new rule.
- A new mute duration applies to the next button press. It does not change a
  mute period that is already active.
- Mute stops the light and buzzer alarm outputs. It does not stop sound
  observations or Bluetooth history updates.
- Hold the mute button for two seconds to disable or enable Bluetooth. A long
  press does not change the mute state. The device saves the Bluetooth state
  and uses it after each restart.
- When Bluetooth becomes enabled, the lights change from off to Bluetooth blue
  during two seconds. When Bluetooth becomes disabled, the lights change from
  Bluetooth blue to off during two seconds.
- A second mute-button press within 750 ms ends mute. A later single press
  restarts the complete mute period.

The buzzer volume is a software request. The hard switch in the buzzer power
wire stays the final control and can stop all buzzer output.

## Bluetooth service

The device advertises a name in the form `ESPNoise-<name>`. The default name
is `Device XXXX`, where `XXXX` is the low four hexadecimal digits of the ESP32
hardware identifier. The `ESPNoise-` prefix stays present after a name change,
so AccessorySetupKit discovery continues to work.

| Item | UUID |
| --- | --- |
| Settings service | `3F751B85-D1AC-4699-AEEC-8B5B720B706B` |
| Configuration | `0235A089-40E1-4985-A78B-046EA4D983A9` |
| Status | `214F1B5A-DD35-4626-8247-FA07DA61EE64` |
| Device name | `AC1D60EF-369C-4640-8055-506A1514BD49` |
| Noise analytics | `7D4677B7-4B75-4BC8-90A8-0954BFF64EB1` |

The configuration value is a 32-byte, little-endian packet.

| Byte | Value |
| ---: | --- |
| 0 | Protocol version, `2` |
| 1 | Flags; bit 0 enables noise analytics collection |
| 2 | LED brightness percent |
| 3 | Buzzer volume percent |
| 4-5 | Green threshold in signed tenths of one dBFS |
| 6-7 | Orange threshold in signed tenths of one dBFS |
| 8-9 | Red threshold in signed tenths of one dBFS |
| 10-13 | K in milliseconds |
| 14-17 | N in milliseconds |
| 18-21 | Decision window in milliseconds |
| 22 | X in percent |
| 23 | Reserved, `0` |
| 24-27 | Mute duration in seconds |
| 28-31 | Phone revision |

The settings fingerprint is FNV-1a 32 over bytes 0 through 27. The revision is
not part of the fingerprint.

When bit 0 is clear, the firmware stops analytics collection and erases its
saved analytics history. When bit 0 is set, collection starts with an empty
current summary if the prior effective value was off.

The firmware also accepts a version 1 configuration packet. Version 1 has no
analytics switch, and analytics collection stays on.

The device-name value is a 20-byte packet. Reads and writes require an
encrypted connection. The app normally uses the separate device-name
characteristic. It can also write this packet to the configuration
characteristic. This fallback lets an iPhone with an old Bluetooth service
cache synchronize the name without a new pairing.

| Byte | Value |
| ---: | --- |
| 0 | Name protocol version, `1` |
| 1 | UTF-8 name length, from `1` through `18`; `0` requests a readback |
| 2-19 | Name bytes and zero padding |

The BLE callback validates and queues a nonempty name. A packet with a zero
length requests the current name. The main loop saves a new name before the
firmware changes the advertised name and sends an exact readback. A BLE write
response alone is not a successful name synchronization.

The current status value is a 20-byte, little-endian packet.

| Byte | Value |
| ---: | --- |
| 0 | Status protocol version, `2` |
| 1 | Alarm state |
| 2 | Mute, sampling, alarm-active, and measurement-valid flags |
| 3 | Error code |
| 4-7 | Applied phone revision |
| 8-11 | Settings fingerprint |
| 12-13 | Current observation maximum in signed tenths of one dBFS |
| 14-15 | Measurement sequence |
| 16 | Saved observation count |
| 17 | Saved observations at or above Green |
| 18 | Saved observations at or above Orange |
| 19 | Saved observations at or above Red |

The 20-byte value fits the default Bluetooth LE notification payload. Live
measurement changes are limited to four notifications each second. A control
state change can send an immediate notification. An unchanged status has a
ten-second heartbeat. The app can also read the old 16-byte status version,
but that version has no measurement graph data.

The noise analytics request is a 12-byte, little-endian packet.

| Byte | Value |
| ---: | --- |
| 0 | Protocol version, `2` |
| 1 | Request type, `1` |
| 2-5 | Last completed sequence that the phone has, or `0` |
| 6-9 | Current UTC time in Unix seconds |
| 10-11 | Reserved, `0` |

The device first notifies the current partial summary. It then sends each newer
completed summary. Each notification is 20 bytes.

If iOS has an old Bluetooth service cache, the app sends the same request to
the configuration characteristic. The device sends the same notifications on
that characteristic. This fallback does not change the packet layout.

| Byte | Value |
| ---: | --- |
| 0 | Protocol version, `2` |
| 1 | Bit 0 is set for the current partial summary |
| 2-5 | Summary sequence |
| 6-9 | Summary start time in UTC Unix seconds |
| 10-11 | Summary duration in seconds |
| 12-13 | Average positive relative level in tenths |
| 14-15 | Peak positive relative level in tenths |
| 16 | Green time in five-second units |
| 17 | Orange time in five-second units |
| 18 | Red time in five-second units |
| 19 | Reserved, `0` |

Error code `1` means that the device could not save the settings. The app keeps
the change pending and does not report a successful synchronization.

The app subscribes to notifications before it writes. It uses a write with a
Bluetooth response. The firmware applies a valid packet in its main task, at
a safe detector boundary. The firmware then notifies the app and supplies the
same packet through a configuration read.

## Pairing and background limits

The app uses AccessorySetupKit on iOS 18 or later. A device with no saved bond
keeps first pairing available. After the first bond succeeds, a different
phone can pair during the first two minutes after device startup. The device
then changes to slower connectable advertising for lower radio use and
known-phone reconnection.

iOS Bluetooth work is event driven. iOS does not guarantee that the app will
run at a fixed time. The app uses Bluetooth restoration and automatic
reconnection, but synchronization can stop in these cases:

- The user force-quits the app.
- Bluetooth is off or permission is removed.
- The phone is out of range.
- The phone restarted and was not unlocked.
- The app was removed or its development signature expired.

Open the app once after these conditions. The device continues to use its last
saved profile when the app is not available.

## Physical acceptance tests

Bluetooth and AccessorySetupKit need a physical iPhone. Test these cases before
release:

1. Add one device during its startup pairing window.
2. Change a global value and confirm that it saves and the device applies it
   without a separate save action.
3. Add an override and confirm that a later global change does not replace it.
4. Change a setting while the device is off. Start the device and confirm an
   immediate synchronization.
5. Move the device out of range and back into range.
6. Add at least three devices and change one device at a time.
7. Remove one device and confirm that the other devices stay connected.
8. Test locked-phone restoration separately from an intentional force-quit.
9. Confirm with a radio scanner that the name and service UUID are present.
10. Confirm that live maxima and threshold counts update during observations.
11. Confirm that the battery build never drives the LEDs above its safe limit.
12. Leave a device out of range for at least one hour. Reconnect it and confirm
    that the app receives the missing completed summaries.
13. Select one device, a group, and all devices on the analytics page. Confirm
    that each chart uses the selected devices only.
14. Disable analytics globally. Confirm that each device stops collection and
    that a device override can enable collection for one device.
15. Hold the mute button for two seconds. Confirm the blue light change, no
    radio advertising, and the saved state after a restart. Repeat the hold to
    enable Bluetooth.

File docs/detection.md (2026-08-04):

# Noise detection and adjustment

## Definition of noise

When there is no alarm, the detector listens for K seconds in each N-second
period. It saves the maximum dBFS frame level from that observation. The
default history contains the six observation maxima from the last minute.

```text
level ratio = observations at or above the level threshold / saved observations
```

The detector requires a complete history before it can start an alarm. It
checks red first, then orange, then green. A level starts when at least X
percent of the saved maxima are at or above that level threshold. With six
observations and X set to 50%, at least three observations must cross a
threshold.

When the alarm is active, the detector makes frequent one-second observations.
It saves each maximum in the same six-value rolling history. After each
observation, it checks the Green, Orange, and Red counts again. The highest
threshold with at least three values sets the output. No single observation
can change the output to a higher level.

One normal observation cannot start a light or buzzer warning. Only the
rolling decision can start a warning. Thus, one cough, dropped object, or other
sporadic sound does not make the sign flash.

## Default values

| Parameter | Meaning | Default |
| --- | --- | ---: |
| K | Observation time | 1 second |
| N | Time from one observation start to the next | 10 seconds |
| Decision window | Saved observation history | 60 seconds |
| History size | Decision window divided by N | 6 observations |
| Minimum history | Observations required before an alarm | 6 observations |
| X | Saved maxima required to start | At least 50%, or 3 of 6 |
| Green threshold | Noise, but not very loud | -55 dBFS |
| Orange threshold | Loud noise | -48 dBFS |
| Red threshold | Very loud noise | -42 dBFS |
| Saved statistic | Value from each observation | Maximum dBFS |
| Microphone settling time | Ignored time before each observation | 300 ms |
| Active-alarm observation | Listening time during an alarm | 1 second |
| Output window | Time for the buzzer pattern | 250 ms |
| Buzzer settling gap | Silence before microphone start | 100 ms |
| Frame | One I2S read block | About 8 ms |

The device takes its first observation immediately after startup. It then
takes one observation every ten seconds. The lights and buzzer stay off during
normal observations. When the rolling history starts an alarm, the firmware
repeats this active-alarm cycle:

1. Give the level-specific output for 250 ms.
2. Listen for one second with the buzzer off.
3. Keep the lights flashing during the check.
4. Save the maximum and remove the oldest value from the six-value history.
5. Set the output to the highest threshold that has at least three values.
6. Stop the alarm when fewer than three values reach Green.
7. Return to the normal N-second schedule after the alarm stops.

The firmware never commands the buzzer on while an audio check is active. It
adds the 100 ms settling gap after each buzzer window, starts the microphone,
and discards another 300 ms of warm-up audio before it measures a sample. This
prevents the louder buzzer and its short case vibration from entering the
noise result.

## Alarm levels and patterns

The highest rolling threshold with at least three of six observations always
sets the alarm level. During an active alarm, each one-second maximum replaces
the oldest value before the firmware calculates the three counts again.

| Level | Light | Buzzer pattern |
| --- | --- | --- |
| Green | Green, slow blink | Silent |
| Orange | Orange, medium blink | Two notes at 1,500 Hz |
| Red | Red, fast blink | Three faster notes at 2,400 Hz |

The alarm output uses the rolling level. A Green alarm stays Green while the
Orange and Red counts stay below the trigger count. The buzzer uses the 50%
electrical tone amplitude. The physical switch can disable all buzzer sounds.

## Configuration values

All default detection, release, color, blink, and buzzer-pattern values are in
`firmware/include/config.h`. The phone app can replace the main runtime values.
The firmware validates and saves the complete profile before it uses it. The
main values are:

```cpp
constexpr int16_t kGreenThresholdDbfsX10 = -550;
constexpr int16_t kOrangeThresholdDbfsX10 = -480;
constexpr int16_t kRedThresholdDbfsX10 = -420;
constexpr uint32_t kMicrophoneWarmupMs = 300;
constexpr uint32_t kSampleDurationMs = 1UL * 1000UL;    // K
constexpr uint32_t kSamplePeriodMs = 10UL * 1000UL;     // N
constexpr uint32_t kDecisionWindowMs = 60UL * 1000UL;
constexpr float kTriggerSampleRatio = 0.50F;            // X
constexpr size_t kHistorySampleCount = 6;
constexpr size_t kMinimumHistorySamples = 6;
constexpr uint32_t kAlarmActiveSampleDurationMs = 1000;
constexpr uint32_t kAlarmOutputWindowMs = 250;
constexpr uint32_t kBuzzerSettleMs = 100;
constexpr uint8_t kBuzzerVolumePercent = 50;
```

K must be greater than zero and must not be greater than N. The decision window
must be a multiple of N. The compiled X ratio is from zero through one. The
runtime X value is an integer percent from 1 through 99. The thresholds must
increase from green to orange to red. The firmware checks these limits and the
buzzer pattern duration at startup.

## Why this rule helps

A short event can make one saved maximum high. It cannot start the alarm by
itself because three of six saved maxima must be high. Sustained loud speech or
other repeated noise is more likely to affect three observations and start the
warning.

The default schedule observes only one second in every ten seconds. It can miss
sound that occurs in the nine-second gaps. If the prototype misses real
coworking conversations, first change N from ten seconds to five seconds. This
gives 12 observations per minute and 20% time coverage.

An absolute maximum is also sensitive to a cough, chair movement, or dropped
object during an observation. The rolling majority limits this effect. If
sporadic events still affect too many observations, a later test can compare
the maximum with a 90th-percentile observation value.

## First test

1. Build the microphone and ESP32 only.
2. Upload the firmware.
3. Open the serial monitor at 115200 bit/s.
4. Read the level during a quiet sample.
5. Record six observations in a normal quiet room.
6. Make one short loud sound and confirm that it does not start the alarm.
7. Make sustained coworking noise through at least three observations.
8. Compare the saved green, orange, and red percentages.
9. Adjust the thresholds, observation period, and X.
10. Connect the LED circuit and repeat the test.
11. Connect the buzzer last.

The serial output gives the maximum dBFS value from each observation. It also
gives the history count, green, orange, and red observation percentages, alarm
state, and selected level.

## Calibration to dBA

The nominal INMP441 sensitivity is -26 dBFS at 94 dB SPL. This gives a rough
conversion of `dB SPL = dBFS + 120`. Thus, -48 dBFS can be near 72 dB SPL. The
module, case, microphone direction, and frequency response cause error. Do not
call this value dBA until you calibrate it.

Use a sound level meter next to the case microphone hole. Use a steady sound.
Do not use speech for calibration.

1. Record the sound level meter value.
2. Record the ESPNoise dBFS value at the same time.
3. Calculate `offset = meter dBA - ESPNoise dBFS`.
4. Repeat at three sound levels.
5. Use the average offset only if the three offsets are close.

The firmware does not contain a full A-weighting filter. The offset is a room
adjustment, not a laboratory calibration.

## Production case adjustment

The production case adjustment on 2026-08-03 used one 10-second target sample
for each alarm level. Each result was the median of ten consecutive one-second
maxima. This method used the installed microphone and case.

| Target | Median | One-second range |
| --- | ---: | ---: |
| Green | -50.7 dBFS | -53.9 to -43.7 dBFS |
| Orange | -48.3 dBFS | -53.0 to -45.5 dBFS |
| Red | -40.5 dBFS | -45.6 to -35.0 dBFS |

After review of the test, the selected thresholds are -55 dBFS for green,
-48 dBFS for orange, and -42 dBFS for red.

The green and orange ranges overlap. The rolling decision limits the effect of
one short peak because at least three of six observations must cross a
threshold. Check the levels again during a normal coworking test.

## Mute and buzzer controls

- Press the mute button to stop the alarm outputs for 30 minutes.
- Sound observations and Bluetooth history continue at the normal interval.
- Press the button a second time within 750 ms to end mute.
- A single press after 750 ms starts a new 30-minute period.
- When mute ends, a saved history above a threshold starts the alarm again.
- Turn the buzzer switch off to cut buzzer power at any time.
- The buzzer switch does not change the light alarm.

## Privacy

The firmware does not save, send, or classify speech. It changes each audio
frame into one energy value and then discards the audio samples.

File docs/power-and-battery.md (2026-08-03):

# Power and battery

## USB-powered option

Use the full-size USB-C ESP32 without a battery. A separate two-wire USB-C
connector supplies the common 5 V rail. The rail splits to the ESP32 `5V` or
`VIN` pin and to the peripheral rail through a 0.5 A resettable fuse.

Use a regulated 5 V supply that can give at least 2 A. A 5 V, 3 A supply gives
useful margin. Do not connect another power source to the ESP32 5 V or 3.3 V
pin.

Test the two-wire connector with a USB-C to USB-C cable before use. If it gives
5 V in both plug orientations, it already has a suitable sink circuit. If it
gives zero volts, use a USB-A to USB-C source or replace it with a two-wire
module that states that it has 5.1 kohm CC resistors.

The ESP32 chip and development board do not supply LED current. Both branches
receive 5 V directly from the two-wire power module. This star connection is
suitable for the first build with 10 pixels. A full-brightness test of the ten
pixels passed. It also makes a later power-module change easier.

The built-in ESP32 USB-C connector is used only for service. Disconnect the
two-wire power module before you connect the service port to a computer.

Use this conservative first-build budget:

| Load | Design allowance |
| --- | ---: |
| ESP32 board and microphone | 350 mA |
| Ten SK6812 RGBW pixels with the production colors at the 100% limit | 600 mA |
| Buzzer and level buffer | 50 mA |
| Total design allowance | 1,000 mA |

The 2 A supply rating gives margin for cable loss and startup current. Measure
the real value with a USB power meter.

## WEMOS battery option

```mermaid
flowchart LR
  WALL["External USB-C, 5 V"] --> PANEL["USB-C to Micro-USB panel cable"]
  PANEL --> WEMOS["WEMOS LOLIN32 Lite"]
  BAT["Protected 3.7 V 10 Ah LiPo"] -->|"PH-2 socket"| WEMOS
  BAT --> BOOST["GPIO-switched TPS61023 boost"]
  BOOST -->|"5.2 V through 0.5 A fuse"| LOADS["SK6812, level buffer, and buzzer"]
  WEMOS -->|"3.3 V"| MIC["INMP441"]
```

The WEMOS stays inside the enclosure. Its built-in charger charges the
internal battery. The external USB-C panel connector is the only connector
necessary for power, charge, firmware upload, and the serial monitor.

The WEMOS charger current is approximately 500 mA. It is suitable for the
selected protected 1S battery, but it is slow. A 10,000 mAh battery has a
minimum ideal charge time of 20 hours. Allow 20 to 24 hours, and allow more
time if the device operates while it charges.

The charger is a simple linear charger. It is not a high-current USB power-bank
circuit. A continuous load can delay charge completion. Keep the alarm off
during the first full charge test. Confirm that the battery and charge circuit
do not become hot.

## Why the boost module is necessary

The WEMOS operates directly from the 3.0 V to 4.2 V battery range. The SK6812
strip needs a stable supply near 5 V. The WEMOS 3.3 V regulator cannot supply
the strip. Some LOLIN32 Lite versions do not expose a useful 5 V output when
they operate from the battery.

The TPS61023 module changes the battery voltage to approximately 5.2 V. GPIO13
enables it only during an alarm or an output test. The module has load
disconnect and a low shutdown current. Thus, the strip and buzzer do not drain
the battery between alarms.

Ten SK6812 RGBW pixels at the 25% firmware limit have a conservative maximum
estimate of approximately 200 mA at 5 V. The buzzer and level buffer add less
than 40 mA. This is below the selected boost module rating, but the value must
be confirmed with a current test.

## Battery pack

Use one factory-assembled 1S LiPo pack with these properties:

- Nominal voltage: 3.7 V
- Full voltage: 4.2 V
- Capacity: 10,000 mAh
- Size code: 1260110, approximately 12 mm by 60 mm by 110 mm
- Built-in PCM protection
- JST-PH 2.0 plug with confirmed polarity
- Charge-current rating of at least 0.5 A
- Discharge-current rating of at least 1 A

The pack stores approximately 37 Wh. Do not connect two packs in parallel.
Do not use a raw cell or loose cylindrical cells.

## Expected run time

The firmware stops the microphone clock between sound samples. It does not use
application light sleep because Bluetooth must stay available. NimBLE can use
controller modem sleep. The WEMOS still powers its CH340 USB bridge, regulator,
and LEDs. These parts set the minimum current.

With the default `K = 1 second` and `N = 10 seconds`, use four to twelve days
only as a first estimate. A noisy room can reduce this time because the alarm
keeps the processor, boost module, and LEDs active. A measured low sleep
current can make a longer time possible.

| Change | Battery effect |
| --- | --- |
| Increase K | More active time and less battery time |
| Decrease N | More samples and less battery time |
| Increase N | Fewer samples and more battery time |
| Keep an alarm active | Much less battery time |
| Increase LED brightness | Much less battery time during an alarm |
| Keep Bluetooth advertising or connected | Less battery time |

Measure battery current at these points before you make a run-time claim:

1. Between samples with the boost off
2. During the one-second microphone observation
3. During a green alarm
4. During a red alarm with the buzzer switch on
5. During USB charge with the alarm off
6. While Bluetooth advertises with the phone out of range
7. While Bluetooth stays connected to the phone

## Enclosure rules

- Put the battery in a separate compartment.
- Use a removable cover with screws.
- Leave at least 2 mm of free space on each flat side of the pouch.
- Do not bend, clamp, glue, or puncture the pouch.
- Keep screw tips, sharp printed edges, and solder joints away from the pouch.
- Add ventilation slots near the WEMOS charge circuit.
- Keep the battery away from direct sun and other heat sources.
- Stop use if the battery becomes hot, changes shape, leaks, or smells.
- Do not charge the unit without supervision until charge tests are complete.

## Limits

The WEMOS built-in charger is useful and removes a separate charge board. Its
500 mA charge rate is the main compromise with a 10,000 mAh battery. The
development board also has more sleep current than a custom low-power board.
For reliable operation for several weeks, measure the prototype first. A later
custom board can remove the USB bridge and power LED.

## Sources

- [WEMOS D32 battery and charge data](https://www.wemos.cc/en/latest/d32/d32.html)
- [TPS61023 product data](https://www.ti.com/product/TPS61023)
- [SK6812 RGBW data sheet](https://cdn-shop.adafruit.com/product-files/2757/p2757_SK6812RGBW_REV01.pdf)
- [LiPo protection guidance](https://learn.adafruit.com/li-ion-and-lipoly-batteries/protection-circuitry)
- [CPSC high-energy battery standards](https://www.cpsc.gov/Regulations-Laws--Standards/Voluntary-Standards/Batteries-Fire-High-Energy-Density)

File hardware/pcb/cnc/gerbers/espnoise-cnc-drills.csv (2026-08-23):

diameter_mm | x_mm | y_mm | purpose
0.8 | 9.500 | 3.000 | wire-via
0.8 | 14.500 | 3.000 | wire-via
0.8 | 3.750 | 4.000 | wire-via
0.8 | 29.000 | 9.500 | wire-via
0.8 | 34.500 | 10.500 | wire-via
0.8 | 57.250 | 12.250 | BZ1-2
0.8 | 57.250 | 12.250 | wire-via
0.8 | 63.750 | 12.250 | BZ1-1
0.8 | 63.750 | 12.250 | wire-via
0.8 | 38.000 | 12.500 | wire-via
0.8 | 19.250 | 18.250 | wire-via
0.8 | 33.500 | 18.250 | wire-via
0.8 | 17.500 | 22.000 | wire-via
0.8 | 29.250 | 22.000 | wire-via
0.8 | 36.750 | 22.000 | wire-via
0.8 | 43.500 | 22.000 | wire-via
0.9 | 48.500 | 6.000 | R2-1
0.9 | 55.500 | 6.000 | R2-2
0.9 | 48.500 | 10.000 | R3-1
0.9 | 48.500 | 16.000 | R3-2
0.9 | 56.460 | 17.000 | Q1-1
0.9 | 59.000 | 17.000 | Q1-2
0.9 | 61.540 | 17.000 | Q1-3
0.9 | 55.500 | 21.000 | D1-2
0.9 | 65.500 | 21.000 | D1-1
1.0 | 9.500 | 3.000 | F1-1
1.0 | 14.500 | 3.000 | F1-2
1.0 | 32.960 | 8.440 | MIC1-1
1.0 | 35.500 | 8.440 | MIC1-2
1.0 | 38.040 | 8.440 | MIC1-3
1.0 | 4.500 | 9.750 | SW2-1
1.0 | 6.500 | 9.750 | SW2-2
1.0 | 8.500 | 9.750 | SW2-3
1.0 | 15.500 | 9.750 | SW1-1
1.0 | 17.500 | 9.750 | SW1-2
1.0 | 19.500 | 9.750 | SW1-3
1.0 | 4.500 | 14.750 | SW2-4
1.0 | 6.500 | 14.750 | SW2-5
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

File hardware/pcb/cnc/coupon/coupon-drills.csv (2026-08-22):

diameter_mm | x_mm | y_mm | purpose
2.0 | 15.000 | 2.000 | registration
2.0 | 15.000 | 13.000 | registration
0.8 | 8.000 | 7.500 | via test
0.8 | 22.000 | 7.500 | via test
0.9 | 5.000 | 7.500 | 0.9 mm fit test
1.0 | 12.000 | 7.500 | 1.0 mm fit test

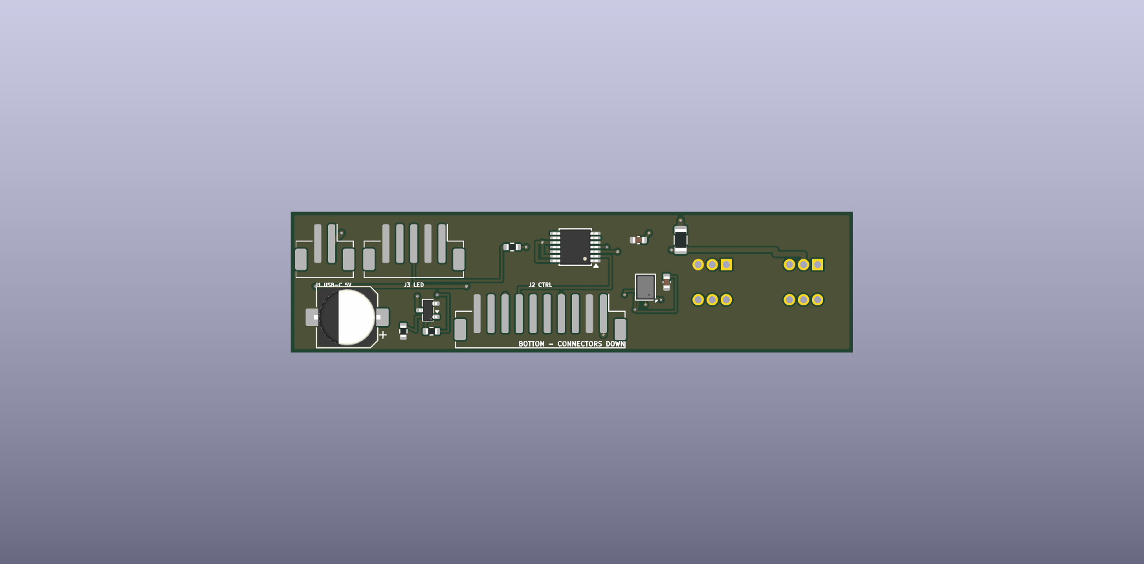
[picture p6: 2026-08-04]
hardware/pcb/jlcpcb/espnoise-carrier-bottom.png

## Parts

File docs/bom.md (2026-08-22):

# Bill of materials

This bill of materials is for one USB-powered production unit. Match the
written part specification. Seller names and listing titles can be incorrect.

## Controller and display

| Qty | Part | Required specification |
| ---: | --- | --- |
| 1 | ESP32 development board | Full-size ESP32, USB-C service port, `esp32dev` PlatformIO support |
| 1 | Digital microphone | TDK InvenSense ICS-43434, I2S, LCSC C5656610; factory placed on the carrier |
| 10 | Addressable pixels | SK6812 RGB plus warm-white, 5 V, 32-bit data; normally cut from a 60-pixel/m strip |
| 1 | Data buffer | SN74AHCT125PWR, TSSOP-14; the part number must include `AHCT` |
| 1 | Data resistor | 330 ohm, 0603; factory placed on the carrier |
| 2 | Bypass capacitor | 100 nF ceramic, 0603; factory placed on the carrier |
| 1 | LED rail capacitor | 1,000 uF, 10 V, 105 degrees C; factory placed on the carrier |

Ten pixels from a 60-pixel/m strip have a nominal length of 166.7 mm. Cut only
at a marked cut line. Keep the data arrows in the direction from `DIN` to
`DOUT`.

## Controls and sound

| Qty | Part | Required specification |
| ---: | --- | --- |
| 1 | Mute button | SHOU HAN 7-7 WS, momentary DPDT, LCSC C5379890 |
| 1 | Buzzer switch | SHOU HAN 7-7 ZS, latching DPDT, LCSC C5379891; use one pole in the buzzer 5 V wire |
| 1 | Buzzer | FUET-1370F-05, passive electromagnetic, 5 V, 2.4 kHz, LCSC C2690507 |
| 1 | Driver transistor | MMBT3904 NPN, LCSC C181119 |
| 1 | Base resistor | 1 kohm, 0603, LCSC C21190 |
| 1 | Flyback diode | 1N5819WS, LCSC C191023 |

The buzzer switch is a hard power cut. Do not replace it with a software-only
control. The factory assembly places the transistor and diode. Check their
orientation in the JLCPCB preview.

## Power

| Qty | Part | Required specification |
| ---: | --- | --- |
| 1 | Wall supply | Regulated 5 V, 2 A minimum; 5 V, 3 A recommended; approved for the country of use |
| 1 | External power cable | USB-C to USB-C, rated for at least 3 A |
| 1 | External power socket | Power-only USB-C input with one 5.1 kohm CC pull-down on CC1 and one on CC2 |
| 1 | Service cable | USB data cable for firmware upload through the ESP32 port |
| 1 | Removable power connector | Two pins, 5 V and GND, rated for at least 2 A |
| 1 | Resettable fuse | MF-R050 or equivalent, 0.50 A hold |

Keep the external power input separate from the ESP32 service port. Do not
combine CC1 and CC2. Disconnect the external power connector before you attach
the ESP32 service cable to a computer.

A supply rated for 3 A does not force 3 A through the circuit. The circuit
takes the current that it needs. Do not use a 6 V to 30 V buck converter in
this 5 V build.

## Assembly

| Qty | Part | Required specification |
| ---: | --- | --- |
| 1 | Carrier PCB | `hardware/pcb/espnoise-carrier.kicad_pcb`; use the Gerber ZIP, BOM, and CPL in `hardware/pcb/jlcpcb` |
| As needed | Module connectors | Keyed connectors, with different pin counts where practical |
| As needed | Power wire | 22 AWG stranded copper, red and black |
| As needed | Signal wire | 26 AWG stranded copper, multiple colors |
| As needed | Heat-shrink tube | 2:1 ratio, sizes that fit the joints |

The production carrier uses bottom-entry JST PH cable interfaces. The adapter
pin orders and cable housings are in `hardware/pcb/controller-adapters.md`.

The home-milled Rev C prototype has a separate BOM in
`hardware/pcb/cnc/espnoise-cnc-bom.csv`. It uses through-hole parts and
individual solder-wire pads. Its microphone pin pattern and buzzer dimensions
come from the prototype parts. The microphone acoustic hole is at the module
center. Use the 1:1 part check before the final CNC build. Do not use the Rev B
JST-PH cable housings on Rev C.

## Optional battery build

The battery build is not necessary for the production enclosure. Do not add it
until the USB-powered unit is stable and its current is measured.

| Qty | Part | Required specification |
| ---: | --- | --- |
| 1 | Controller | WEMOS LOLIN32 Lite V1.0.0 with its on-board charger |
| 1 | Battery pack | One protected 3.7 V LiPo pack with built-in protection and the correct connector polarity |
| 1 | Boost module | TPS61023, 5.2 V output, with an accessible enable input |
| 1 | Enable resistor | 100 ohm, 0.25 W |
| 1 | Enable pull-down | 100 kohm, 0.25 W |

Use a complete protected pack. Do not use a raw pouch cell or loose 18650 or
21700 cells. Confirm the connector polarity with a multimeter before you
connect the pack. The battery-build 5 V boost must stay off when there is no
alarm.

## Tools

- Soldering iron with a small tip
- Multimeter
- USB power meter
- Wire cutter and wire stripper
- Heat gun for heat-shrink tube
- Sound level meter for dBA calibration
- Caliper for part and enclosure checks

## Technical sources

- [ESP32-DevKitC documentation](https://docs.espressif.com/projects/esp-dev-kits/en/latest/esp32/esp32-devkitc/user_guide.html)
- [ICS-43434 data sheet](https://invensense.tdk.com/wp-content/uploads/2016/02/DS-000069-ICS-43434-v1.2.pdf)
- [SN74AHCT125 data sheet](https://www.ti.com/lit/gpn/SN74AHCT125)
- [SK6812 RGBW data sheet](https://cdn-shop.adafruit.com/product-files/2757/p2757_SK6812RGBW_REV01.pdf)
- [TPS61023 data](https://www.ti.com/product/TPS61023)
- [LiPo protection guidance](https://learn.adafruit.com/li-ion-and-lipoly-batteries/protection-circuitry)
- [CPSC loose-cell warning](https://www.cpsc.gov/Newsroom/News-Releases/2021/CPSC-Issues-Consumer-Safety-Warning-Serious-Injury-or-Death-Can-Occur-if-Lithium-Ion-Battery-Cells-Are-Separated-fro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)

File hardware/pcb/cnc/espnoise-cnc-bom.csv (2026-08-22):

ref | quantity | value | face | footprint | note
SW2 | 1 | BUZZER ENABLE (7-7 ZS) | User | ESPNoise:7x7_DPDT_Pushbutton | Extended state enables buzzer power.
SW1 | 1 | MUTE (7-7 WS) | User | ESPNoise:7x7_DPDT_Pushbutton | Momentary mute button.
MIC1 | 1 | MH-ET LIVE INMP441 2x3 MODULE | User | ESPNoise:MH_ET_LIVE_INMP441_2x3_P2.54_Row7.62 | The printed-label and acoustic-hole face points toward the case top. In that face view, with the notch at the local top edge: top row 1 GND, 2 VDD, 3 SD; bottom row 4 L/R, 5 WS, 6 SCK. L/R is grounded. The pin pitches and centered acoustic hole are confirmed. The 13 mm body is approximate.
BZ1 | 1 | TWO-PIN 5 V BUZZER | User | ESPNoise:Buzzer_THT_2Pin_P6.50mm_D12mm | Passive buzzer with top sound port. Pad 1 is + and pad 2 is -. The measured body is 12 mm, the lead pitch is 6.5 mm, and each lead is 0.5 mm. D1 protects the driver from the coil turn-off pulse.
PWR1 | 1 | 5 V POWER WIRES | Internal | ESPNoise:WirePads_2_P3.5mm | External power-only input. Keep it separate from the ESP32 service port.
J_ESP32 | 1 | ESP32 INDIVIDUAL WIRES | Internal | ESPNoise:IndividualWireGroup_ESP32 | Pins: 1 VIN/5V, 2 GND, 3 3V3, 4 GPIO26 MIC_SCK, 5 GPIO25 MIC_WS, 6 GPIO32 MIC_SD, 7 GPIO18 LED_DATA, 8 GPIO23 BUZZER_PWM, 9 GPIO27 MUTE_N.
J_LED | 1 | LED STRIP INDIVIDUAL WIRES | Internal | ESPNoise:IndividualWireGroup_LED | Pins: 1 +5V, 2 DIN from GPIO18, 3 GND.
R2 | 1 | 1K | Internal | THT:Axial
R3 | 1 | 100K | Internal | THT:Axial
D1 | 1 | 1N5819 | Internal | THT:Axial
F1 | 1 | 0.5A PTC MF-R050 | Internal | THT:Fuse_Radial_P5.00mm
Q1 | 1 | 2N3904 | Internal | THT:TO-92_Inline_EBC | Flat-face pin order is E-B-C. Confirm the transistor data sheet.

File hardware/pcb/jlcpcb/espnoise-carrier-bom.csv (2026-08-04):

Comment | Designator | Footprint | LCSC Part #
0.5A PTC | F1 | Fuse_1206_3216Metric | C163512
1000uF 10V | C2 | CP_Elec_8x10.5 | C5246577
100k | R3 | R_0603_1608Metric | C25803
100nF | C1,C3 | C_0603_1608Metric | C14663
1N5819WS | D1 | D_SOD-323 | C191023
1k | R2 | R_0603_1608Metric | C21190
330R | R1 | R_0603_1608Metric | C23138
BUZZER ENABLE | SW2 | ESPNoise_7x7_DPDT_Pushbutton | C5379891
CONTROLLER | J2 | JST_PH_B10B-PH-SM4-TB_1x10-1MP_P2.00mm_Vertical | C265112
FUET-1370F-05 | BZ1 | ESPNoise_FUET-1370F-05 | C2690507
ICS-43434 | MIC1 | InvenSense_ICS-43434-6_3.5x2.65mm | C5656610
LED STRIP | J3 | JST_PH_B5B-PH-SM4-TB_1x05-1MP_P2.00mm_Vertical | C265086
MMBT3904 | Q1 | SOT-23 | C181119
MUTE | SW1 | ESPNoise_7x7_DPDT_Pushbutton | C5379890
SN74AHCT125PWR | U1 | TSSOP-14_4.4x5mm_P0.65mm | C36365
USB-C 5V | J1 | JST_PH_B2B-PH-SM4-TB_1x02-1MP_P2.00mm_Vertical | C265003

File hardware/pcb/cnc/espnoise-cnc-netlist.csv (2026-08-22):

reference | pin | net | description
SW2 | 4 | +5V_BUZZER_SW | BUZZER ENABLE (7-7 ZS)
SW2 | 5 | +5V_PERIPH | BUZZER ENABLE (7-7 ZS)
SW1 | 5 | MUTE_N | MUTE (7-7 WS)
SW1 | 6 | GND | MUTE (7-7 WS)
MIC1 | 1 | GND | MH-ET LIVE INMP441 2x3 MODULE
MIC1 | 2 | +3V3 | MH-ET LIVE INMP441 2x3 MODULE
MIC1 | 3 | MIC_SD | MH-ET LIVE INMP441 2x3 MODULE
MIC1 | 4 | GND | MH-ET LIVE INMP441 2x3 MODULE
MIC1 | 5 | MIC_WS | MH-ET LIVE INMP441 2x3 MODULE
MIC1 | 6 | MIC_SCK | MH-ET LIVE INMP441 2x3 MODULE
BZ1 | 1 | +5V_BUZZER_SW | TWO-PIN 5 V BUZZER
BZ1 | 2 | BUZZER_COLLECTOR | TWO-PIN 5 V BUZZER
PWR1 | 1 | +5V_IN | 5 V POWER WIRES
PWR1 | 2 | GND | 5 V POWER WIRES
J_ESP32 | 1 | +5V_IN | ESP32 INDIVIDUAL WIRES
J_ESP32 | 2 | GND | ESP32 INDIVIDUAL WIRES
J_ESP32 | 3 | +3V3 | ESP32 INDIVIDUAL WIRES
J_ESP32 | 4 | MIC_SCK | ESP32 INDIVIDUAL WIRES
J_ESP32 | 5 | MIC_WS | ESP32 INDIVIDUAL WIRES
J_ESP32 | 6 | MIC_SD | ESP32 INDIVIDUAL WIRES
J_ESP32 | 7 | LED_DATA | ESP32 INDIVIDUAL WIRES
J_ESP32 | 8 | BUZZER_PWM | ESP32 INDIVIDUAL WIRES
J_ESP32 | 9 | MUTE_N | ESP32 INDIVIDUAL WIRES
J_LED | 1 | +5V_PERIPH | LED STRIP INDIVIDUAL WIRES
J_LED | 2 | LED_DATA | LED STRIP INDIVIDUAL WIRES
J_LED | 3 | GND | LED STRIP INDIVIDUAL WIRES
R2 | 1 | BUZZER_PWM | 1K
R2 | 2 | BUZZER_BASE | 1K
R3 | 1 | BUZZER_BASE | 100K
R3 | 2 | GND | 100K
D1 | 1 | +5V_BUZZER_SW | 1N5819
D1 | 2 | BUZZER_COLLECTOR | 1N5819
F1 | 1 | +5V_IN | 0.5A PTC MF-R050
F1 | 2 | +5V_PERIPH | 0.5A PTC MF-R050
Q1 | 1 | GND | 2N3904
Q1 | 2 | BUZZER_BASE | 2N3904
Q1 | 3 | BUZZER_COLLECTOR | 2N3904

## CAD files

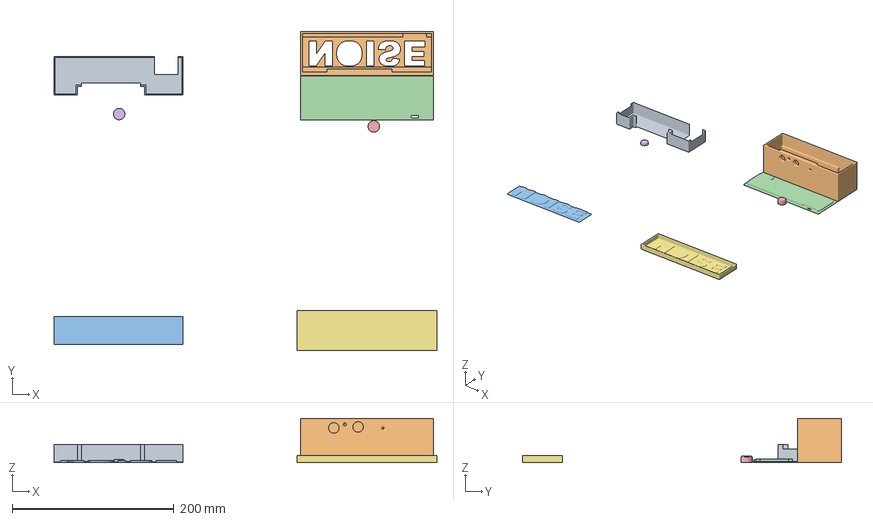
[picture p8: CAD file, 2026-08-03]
cad/production/espnoise.3mf
473.4 x 393.8 x 54.5 mm
Reflector.stl
Case.stl
Letters.stl
Back.stl
Button.stl
Toggle button.stl
Letters mould

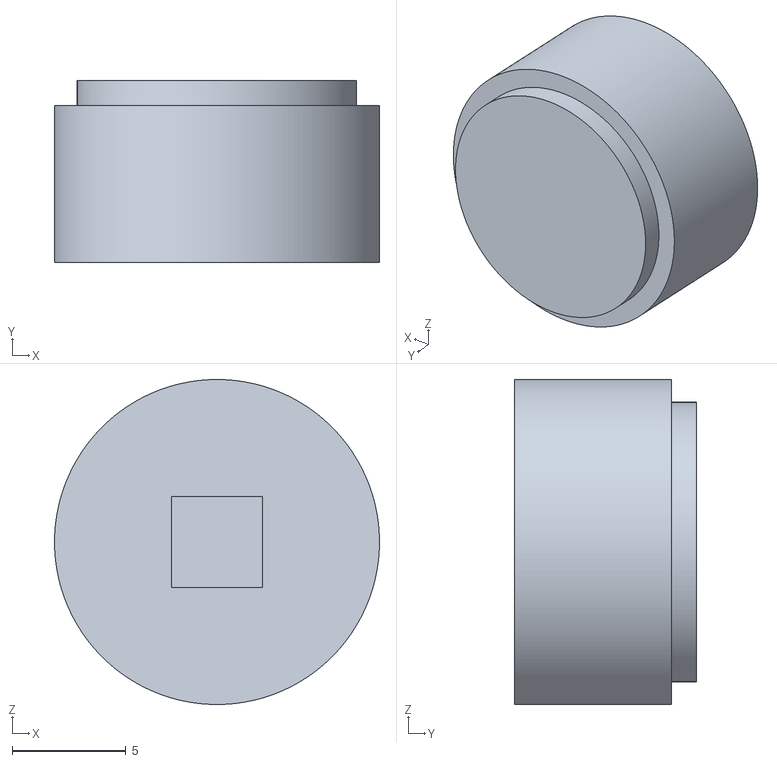
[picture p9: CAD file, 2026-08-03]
cad/production/button.stl
14.3 x 8.00 x 14.3

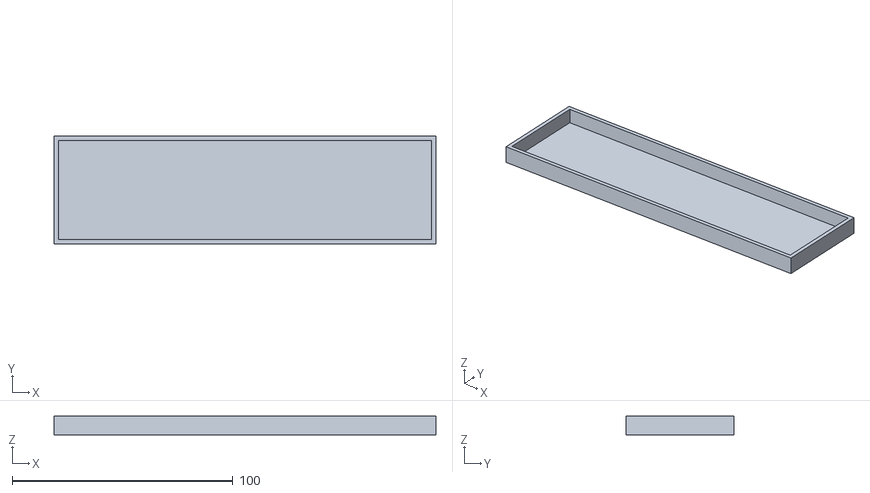
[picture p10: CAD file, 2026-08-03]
cad/production/letters-mould.stl
173.0 x 49.0 x 8.60

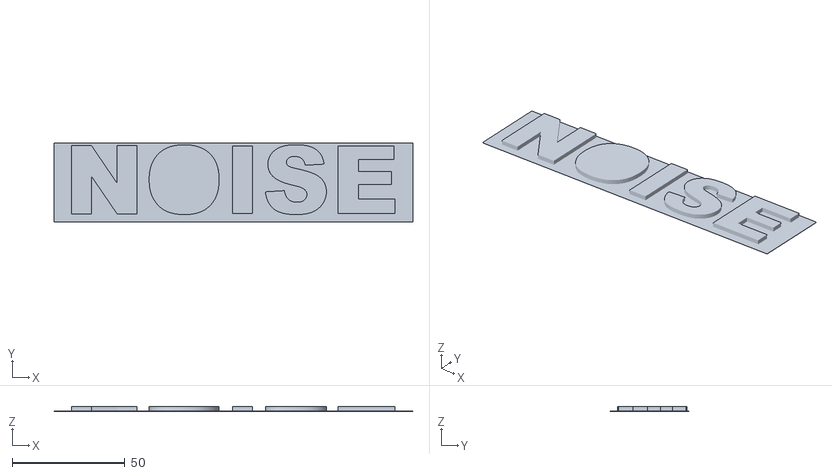
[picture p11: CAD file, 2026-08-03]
cad/production/letters.stl
159.0 x 35.0 x 2.40

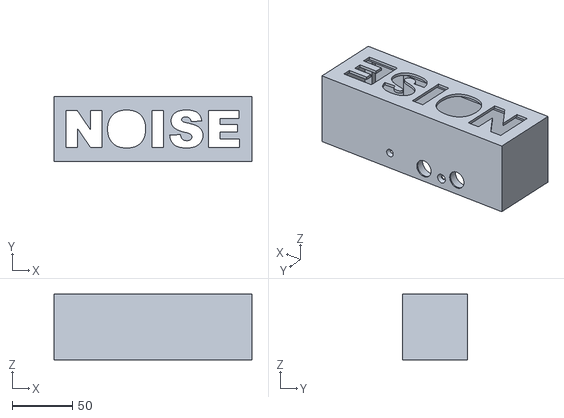
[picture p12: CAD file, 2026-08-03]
cad/production/case.stl
164.0 x 54.0 x 54.5

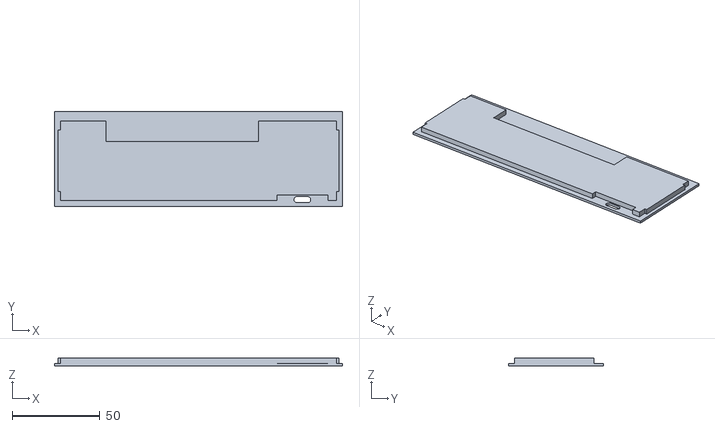
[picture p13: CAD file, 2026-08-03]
cad/production/back.stl
164.0 x 54.0 x 4.40

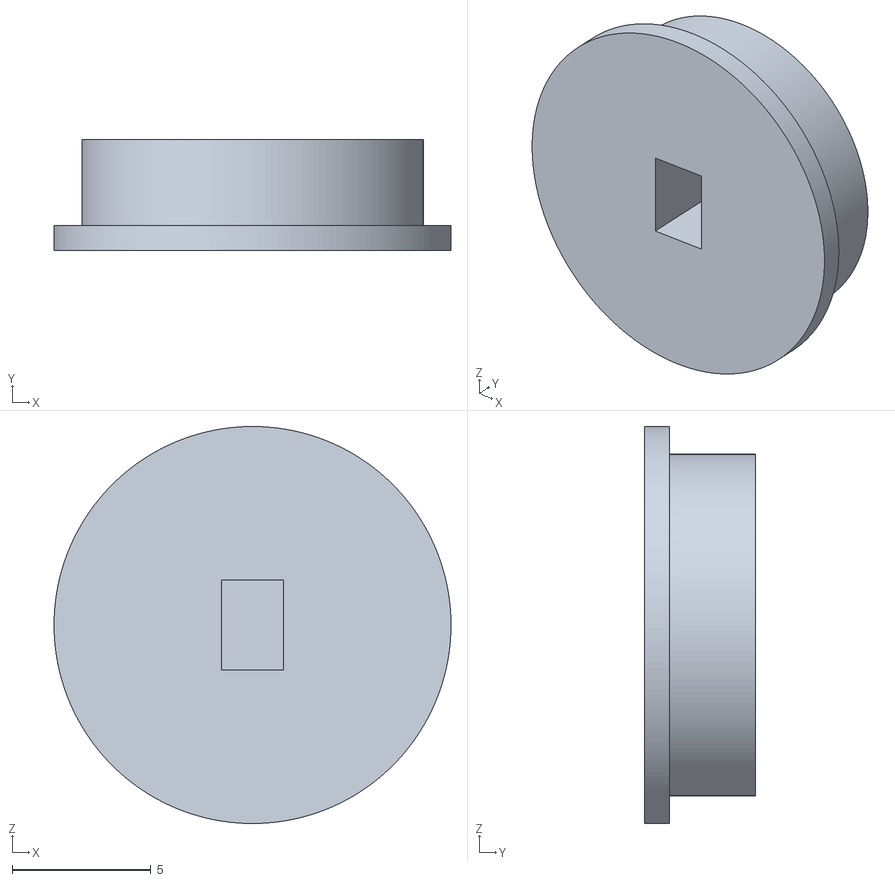
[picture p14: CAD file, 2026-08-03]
cad/production/toggle-button.stl
14.3 x 4.00 x 14.3

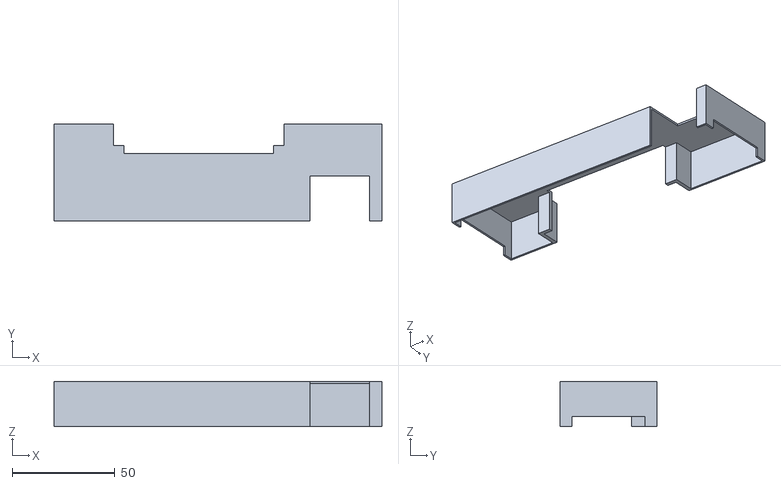
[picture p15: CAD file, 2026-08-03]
cad/production/reflector.stl
159.3 x 47.3 x 22.0

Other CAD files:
cad/production/espnoise.f3d

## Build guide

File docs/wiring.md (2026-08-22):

# Wiring

Both controller options use the same GPIO pins. The pin map avoids the flash
pins and the main startup-configuration pins.

## Pin map

| Function | Module pin | ESP32 pin | Power |
| --- | --- | --- | --- |
| Microphone clock | ICS-43434 SCK | GPIO26 | 3.3 V logic |
| Microphone word select | ICS-43434 WS | GPIO25 | 3.3 V logic |
| Microphone data | ICS-43434 SD | GPIO32 | 3.3 V logic |
| Microphone channel | ICS-43434 L/R | GND | Left channel |
| Sign data | 74AHCT125 input | GPIO18 | 3.3 V to 5 V level change |
| Buzzer control | MMBT3904 base through 1 kohm | GPIO23 | 3.3 V PWM |
| Peripheral power enable | TPS61023 EN | GPIO13 | Battery build only |
| 30-minute mute | Button to GND | GPIO27 | Internal pull-up |
| Buzzer enable | SPST switch in buzzer positive wire | No GPIO | Hard power cut |

## Carrier PCB

The production carrier PCB is in `hardware/pcb`. It keeps the ESP32 removable
and presents controller signals on the 10-pin J2 connector. J1, J2, and J3
are on the lower PCB face, and their cables point down. The microphone and
buzzer are on the PCB.

For the full-size ESP32, connect J2 as follows:

| J2 pin | Signal | ESP32 connection |
| ---: | --- | --- |
| 1 | 5 V input | `5V` or `VIN` |
| 2 | GND | GND |
| 3 | 3.3 V | `3V3` |
| 4 | Microphone clock | GPIO26 |
| 5 | Microphone word select | GPIO25 |
| 6 | Microphone data | GPIO32 |
| 7 | LED data | GPIO18 |
| 8 | Buzzer PWM | GPIO23 |
| 9 | Mute input | GPIO27 |
| 10 | GND | GND |

The carrier is also electrically usable with an ESP32-C3 adapter cable, but
the current firmware does not have an ESP32-C3 build. See
`hardware/pcb/controller-adapters.md` before you make that cable.

The home-milled Rev C board keeps GPIO26, GPIO25, GPIO32, GPIO18, GPIO23, and
GPIO27. It uses individual solder-wire pads. It does not use a JST housing.
Its round MH-ET LIVE INMP441 module has a two-row by three-pin footprint. See
`hardware/pcb/cnc/pinout.md` for every pad and its marked-face orientation.

## USB-powered build

Use this production circuit with the full-size USB-C ESP32. Do not install a
battery. The external USB-C connector carries power only.

```mermaid
flowchart TB
  USB["External two-wire USB-C, 5 V"] --> PLUG["Removable 5 V and GND plug"]
  PLUG --> SPLIT["5 V power split"]
  SPLIT -->|"5 V and GND"| ESP5["ESP32 5V or VIN and GND pins"]
  ESP5 --> ESP["ESP32"]
  SPLIT --> PTC["0.5 A hold fuse"]
  PTC --> V5["5 V peripheral rail"]
  ESP3["ESP32 3V3 pin"] --> MIC["ICS-43434"]
  V5 --> LEVEL["74AHCT125"]
  V5 --> LED["10 SK6812 RGBW pixels"]
  V5 --> SW["Latching hard buzzer switch"]
  SW --> BUZZER["5 V passive magnetic buzzer"]
  ESP -->|"GPIO18"| LEVEL
  LEVEL -->|"330 ohm"| LED
  ESP -->|"GPIO23 PWM through 1 kohm"| DRIVER["MMBT3904 driver"]
  BUZZER --> DRIVER
  DRIVER --> GND["Common GND"]
  ESP -->|"GPIO26, GPIO25, GPIO32"| MIC
  BUTTON["30-minute MUTE button"] -->|"GPIO27 to GND"| ESP
```

Leave GPIO13 disconnected in this build. The firmware can operate the pin,
but the `esp32dev` build does not configure it as a power-control output.

The power input splits before the ESP32. Thus, LED current does not pass
through the ESP32 board. Do not use `3V3` or a GPIO pin for strip power.

The ESP32 built-in USB-C port is a service port. Before you connect it to a
computer, disconnect the removable external-power plug. Do not supply the
ESP32 `5V` or `VIN` pin and its USB port at the same time.

Before you connect the strip, use a multimeter to confirm that the selected
header pin has 4.75 V to 5.25 V relative to GND. Start with one pixel. Then add
the complete 10-pixel section.

Test the external power connector in both cable orientations. Test firmware
upload separately through the ESP32 built-in USB-C port.

## WEMOS battery build

The WEMOS charger supplies the ESP32 from USB or the battery. The switched
boost module supplies the 5 V LEDs, level buffer, and buzzer.

```mermaid
flowchart TB
  USB["External USB-C, 5 V"] --> CABLE["USB-C female to Micro-USB male panel cable"]
  CABLE --> WUSB["WEMOS Micro-USB port"]
  BAT["Protected 3.7 V LiPo"] --> PH2["WEMOS PH-2 battery socket"]
  PH2 --> WEMOS["WEMOS LOLIN32 Lite"]
  PH2 -->|"BAT+ and GND pads"| BOOST["TPS61023 5.2 V boost"]
  WEMOS -->|"GPIO13 through 100 ohm"| EN["Boost EN"]
  EN -->|"100 kohm pull-down"| GND["Common GND"]
  BOOST --> PTC["0.5 A hold fuse"]
  PTC --> V5["Switched 5 V peripheral rail"]
  WEMOS -->|"3V3"| MIC["ICS-43434"]
  V5 --> LEVEL["74AHCT125"]
  V5 --> LED["10 SK6812 RGBW pixels"]
  V5 --> SW["Latching hard buzzer switch"]
  SW --> BUZZER["5 V passive magnetic buzzer"]
  WEMOS -->|"GPIO18"| LEVEL
  LEVEL -->|"330 ohm"| LED
  WEMOS -->|"GPIO23 PWM through 1 kohm"| DRIVER["MMBT3904 driver"]
  BUZZER --> DRIVER
  DRIVER --> GND
  WEMOS -->|"GPIO26, GPIO25, GPIO32"| MIC
  BUTTON["30-minute MUTE button"] -->|"GPIO27 to GND"| WEMOS
```

With the battery disconnected, solder the boost `VIN+` and `GND` wires to the
same WEMOS solder pads as the battery socket. Do not solder wires to the
battery pack. Use 22 AWG wire for these two connections. Confirm the pad
polarity with a multimeter before you solder.

Connect the boost enable circuit as follows:

```text
WEMOS GPIO13 -> 100 ohm -> TPS61023 EN
TPS61023 EN  -> 100 kohm -> GND
```

The pull-down keeps the boost off while the ESP32 starts or resets. Do not use
the WEMOS 3.3 V output or an uncertain 5 V pin to supply the LED strip.

## Digital microphone

The production carrier has an ICS-43434 microphone. Its signals are:

```text
ICS-43434 VDD  -> ESP32 3V3
ICS-43434 GND  -> ESP32 GND
ICS-43434 SCK  -> ESP32 GPIO26
ICS-43434 WS   -> ESP32 GPIO25
ICS-43434 SD   -> ESP32 GPIO32
ICS-43434 L/R  -> GND
```

The microphone is on the lower PCB face. Its acoustic port points through a
0.5 mm PCB hole to the case top. Align the case microphone hole with this PCB
hole. Do not cover it with glue, foam, or a label.

An INMP441 module remains suitable for a hand-wired prototype. It uses the
same SCK, WS, SD, 3.3 V, GND, and L/R signal functions.

The firmware reads both I2S channel slots and uses the slot with the higher
signal. Keep `L/R` connected to GND for a defined channel and stable operation.

## SK6812 level circuit

The SK6812 has a 5 V data input. The production carrier uses an
SN74AHCT125PWR. Do not use a BSS138 I2C level shifter. The AHCT input accepts
the 3.3 V ESP32 signal when the part has a 5 V supply.

```text
SN74AHCT125 pin 14 VCC -> 5 V peripheral rail
SN74AHCT125 pin 7  GND -> GND
SN74AHCT125 pin 1  /OE -> GND
SN74AHCT125 pin 2  1A  -> ESP32 GPIO18
SN74AHCT125 pin 3  1Y  -> 330 ohm -> first SK6812 DIN
100 nF capacitor       -> between pin 14 and pin 7

5 V peripheral rail -> strip +5V at both ends
Common GND           -> strip GND at both ends
First pixel DOUT     -> next pixel DIN
```

Tie unused AHCT inputs to GND. Disable unused outputs with their `/OE` pins at
5 V. Put a 1,000 uF, 10 V capacitor between 5 V and GND near the strip. Check
the capacitor polarity before you apply power.

Most SK6812 RGBW strips use the `GRBW` data order. The firmware uses this order.
If a one-pixel test gives wrong colors, do not change the wiring. Change the
pixel order in `firmware/src/main.cpp` to match the strip data sheet.

## Buzzer circuit

The production carrier uses a 5 V passive electromagnetic buzzer. Use this
circuit:

```text
5 V peripheral rail -> latching hard switch -> buzzer +
Buzzer other pin -> MMBT3904 collector
MMBT3904 emitter -> GND
ESP32 GPIO23 -> 1 kohm -> MMBT3904 base
Flyback diode anode -> MMBT3904 collector
Flyback diode cathode -> switched 5 V
```

GPIO23 sends a 2.4 kHz PWM signal. The 1 kohm resistor limits the transistor
base current. The switch opens the 5 V buzzer supply, so software cannot
override it. D1 absorbs the inductive turn-off pulse from the buzzer coil.
Measure the buzzer current during the first power test.

## Controls

Use one normally-open momentary button. Connect one side to GND and the other
side to GPIO27. One press turns off the alarm outputs for the configured mute
time. Sound observations and Bluetooth history continue at the configured
sample interval. Press the button a second time within 750 ms to end mute. A
single press after this time restarts the complete mute period.

Use the maintained switch as a hard switch for the buzzer. The carrier uses
one pole of a DPDT push-push switch between the 5 V peripheral rail and the
buzzer positive pin. Its extended state connects power and enables the buzzer.
The switch does not use a separate ESP32 input.

## Test order

1. Build and test the ESP32 and microphone.
2. Measure the boost output. It must be from 4.8 V to 5.3 V.
3. Test one SK6812 pixel at the 25% brightness limit.
4. Connect all 10 pixels.
5. Test the magnetic buzzer, MMBT3904, flyback diode, and switch last.
6. Measure current in quiet, sample, and alarm states.

Use one common ground for all parts. Test for a short circuit before you
connect the battery or USB supply.

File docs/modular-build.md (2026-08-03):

# Modular build stages

Do not build all functions at the same time. Complete and test one stage before
you add the next stage.

## Module interfaces

Use plugs between the modules. Do not solder each external module directly to
the ESP32 board.

| Module | Connector | Pins |
| --- | --- | --- |
| 5 V sign power | JST-XH-2 | `5V`, `GND` |
| Microphone | JST-XH-6 | `3V3`, `GND`, `SCK`, `WS`, `SD`, `L/R` |
| LED sign | JST-XH-3 | `5V`, `GND`, `DATA` |
| Mute button | JST-XH-2 | `GPIO27`, `GND` |
| Buzzer | JST-XH-2 | `SWITCHED_5V`, `COLLECTOR` |
| Optional power control | JST-XH-3 | `BAT`, `GND`, `ENABLE` |

Mark pin 1 on each plug and socket. Use different pin counts where possible so
that one module cannot connect to the wrong socket.

The production carrier PCB replaces these prototype plugs with JST PH
connectors. It combines controller signals in J2 and supplies LED power at both
strip ends through J3. Use `hardware/pcb/controller-adapters.md` as the
production connector table. Do not use the prototype JST-XH pin count as a
carrier PCB pin count.

## Stage 0: Two-wire USB-C power module

Test the two-wire USB-C connector before you connect it to the ESP32:

1. Keep its red and black wires disconnected from all circuits.
2. Connect a USB-C to USB-C cable and a 5 V USB-C supply.
3. Measure between the red and black wires.
4. Reverse the USB-C cable plug and measure again.
5. Use the connector if both measurements are from 4.75 V to 5.25 V.

If both measurements are zero, the connector probably has no CC pull-down
resistors. If it exposes separate CC1 and CC2 pads, connect one 5.1 kohm
resistor from each pad to GND. Do not combine CC1 and CC2. If the connector
exposes only red and black wires, the resistors cannot be added to it.

The [USB-C compatibility repair](usb-c-repair.md) is an optional advanced
method. It is not necessary when the input module has the two correct CC
pull-down resistors.

## Stage 1: ESP32 and USB power

Use the full-size USB-C ESP32. Connect no other modules.

1. Connect the two-wire power module red wire to the ESP32 `5V` or `VIN` pin.
2. Connect its black wire to ESP32 GND.
3. Connect a regulated 5 V USB supply rated for at least 2 A.
4. Confirm that the ESP32 starts.
5. Measure from the board `5V` or `VIN` pin to GND.
6. Continue only if the value is from 4.75 V to 5.25 V.

Use a removable two-pin plug between the power module and the rest of the
circuit. Disconnect this plug before you connect the ESP32 service USB port to
a computer.

## Stage 2: Microphone

Connect only the INMP441 module. Upload the `esp32dev` firmware and use the
serial monitor. Confirm that quiet and loud sounds give different dBFS values.

## Stage 3: One LED pixel

Build the AHCT level-change circuit. Connect one SK6812 pixel with the 330 ohm
data resistor, 100 nF AHCT capacitor, and 1,000 uF rail capacitor. Supply it
from the fused peripheral branch of the two-wire power module.

Confirm red, green, blue, and warm-white operation. If the colors are wrong,
change the firmware pixel order. Do not continue until one pixel is correct.

## Stage 4: Complete sign

Connect 10 pixels. Supply 5 V and GND at both ends of the strip. Keep the
firmware brightness at 25% or less. Measure the 5 V rail while the sign flashes.
It must stay above 4.75 V.

## Stage 5: Controls

Add the 30-minute mute button. Test its action during a sample and during an
alarm. Then add the physical buzzer switch and the tested 2N3904 driver
circuit.

## Stage 6: Prototype case

Make a simple test case or open frame. Test the microphone position and the
diffuser before you make the final enclosure.

## Stage 7: Optional battery power

Do not add this stage until the USB-powered unit is stable and its current is
measured. A battery module must present the same 5 V and GND interface to the
sign. The detector and control modules do not change.

If the full-size ESP32 remains in use, the future battery module needs a
protected cell, a charger with load sharing, and a 5 V boost supply. Do not
connect a battery directly to this ESP32 board.

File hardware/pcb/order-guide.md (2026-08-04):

# JLCPCB order guide

The files in `hardware/pcb/jlcpcb` are ready for a JLCPCB PCB and assembly
order. The KiCad design-rule check has zero violations and zero open
connections.

## Files to upload

1. Upload `espnoise-carrier-gerbers.zip` for PCB fabrication.
2. Select PCB assembly for both PCB faces.
3. Upload `espnoise-carrier-bom.csv` as the bill of materials.
4. Upload `espnoise-carrier-cpl.csv` as the component placement file.

Use these PCB options unless JLCPCB finds a technical conflict:

| Option | Value |
| --- | --- |
| Board size | 80 mm by 20 mm |
| Layers | 2 |
| Material | FR-4 |
| Thickness | 1.6 mm |
| Copper | 1 oz |
| Surface finish | Lead-free HASL |
| Solder mask | Green |
| Assembly | Both faces, including through-hole switches |

The design has SMT parts on both faces and through-hole switches on the top
face. JLCPCB states that its current service supports through-hole parts with
manual or wave soldering. Confirm that both switch rows are selected before
payment. If the site does not offer assembly for `C5379890` or `C5379891`, stop
the order. Do not accept a part substitution without a data-sheet and
footprint check.

## Assembly preview checks

Check these items in the online preview:

1. C2 positive is on pad 1 and points towards the PCB center.
2. U1 pin 1 agrees with the square pin-1 mark.
3. J1, J2, and J3 pin 1 agree with the square pad.
4. SW1 is `C5379890`, the momentary `7-7 WS` part.
5. SW2 is `C5379891`, the latching `7-7 ZS` part.
6. J1, J2, J3, MIC1, and C2 are on the bottom face.
7. SW1, SW2, BZ1, and D1 are on the top face.
8. MIC1 pin 1 and D1 cathode agree with the marks in the preview.
9. BZ1 positive pad 1 is on the right side in the top view.

The CPL uses counter-clockwise rotation values, as the JLCPCB placement format
specifies. Bottom parts with a 270 degree value are the flipped form of a
90 degree KiCad placement. The JLCPCB component preview remains the final
orientation check.

## Cost allowance

For a small order of five assembled boards, keep an allowance of approximately
USD 110 to USD 190 before Dubai VAT and import charges. The range includes the
two-face setup, through-hole work, extended-part fees, components, and the PCB
charge. It does not include a controller, LED strip, cables, or power module.
Courier delivery to Dubai is an additional charge.

This is an allowance, not a quote. JLCPCB part stock and shipping prices can
change. The order page gives the valid price after it maps all BOM lines.

JLCPCB gives its current setup, manual assembly, and through-hole service
details in its [PCB assembly FAQ](https://jlcpcb.com/help/article/pcb-assembly-faqs).
It gives the required placement columns in its
[pick-and-place guide](https://jlcpcb.com/help/article/pick-place-file-for-pcb-assembly).

## Mechanical check before the assembled order

Rev B uses an 80 mm by 20 mm outline. The user-facing parts are on the 10 mm
centerline. The board origin is its upper-left corner in the KiCad view. The
important coordinates are:

| Item | X | Y |
| --- | ---: | ---: |
| SW2, buzzer enable | 7.0 mm | 10.0 mm |
| SW1, mute | 20.0 mm | 10.0 mm |
| MIC1 acoustic hole | 29.5 mm | 10.0 mm |
| BZ1, buzzer | 69.0 mm | 10.0 mm |

The PCB has no mounting holes. The case must hold its long edges or use a
printed tray. Before the assembled order, print the top SVG at 100% scale or
order one bare PCB. Put it in the case and check the switch, microphone,
buzzer, connector, capacitor, and cable clearances.

The switch body is nominally 7 mm by 7 mm. Its stem is nominally 3 mm by 2 mm.
Use an initial printed-cap socket of approximately 3.2 mm by 2.2 mm, and adjust
it after a real switch measurement. Keep the round cap at approximately 10 mm
diameter. Do not make a final case model from the nominal stem dimension alone.

Keep a clear sound path above the 0.5 mm microphone hole and above the buzzer
port. Do not put a closed printed button cap over either sound path.

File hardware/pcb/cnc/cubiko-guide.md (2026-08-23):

# Genmitsu Cubiko first PCB guide

Use this guide to put two ESPNoise Rev C units on one blank. The machine files
contain one unit. Do not start with the complete blank. First use the 1:1 part
check. Then use the coupon.

## Tools and material

Use these items:

- Genmitsu Cubiko with its cover, clamps, and height-map cable
- Flat two-face copper-clad FR-4, nominally 70 mm by 50 mm
- Sharp 20-degree or 30-degree V-bit with a 3.175 mm shank
- 0.8 mm, 0.9 mm, 1.0 mm, 1.2 mm, and 2.0 mm carbide drills
- 1.0 mm carbide PCB router bit with a 3.175 mm shank
- Two smooth 2.0 mm registration pins
- Flat sacrificial spoilboard
- Caliper, fine marker, multimeter, and magnifier or USB microscope
- Safety glasses and suitable dust protection
- Small vacuum with a suitable fine-dust filter

Use a 20-degree V-bit first if you have one. A small Z error changes its cut
width less than it changes the cut width of a large-angle bit. A 30-degree
V-bit also works after the coupon passes. Do not use a 60-degree or 90-degree
V-bit for the first panel.

Use the 1.0 mm PCB router bit only for the last separation cut. A corn-cut PCB
router bit is a good type for FR-4. A straight carbide end mill can also work
after a test. Do not use a drill for a side cut. A drill is not made for that
load. Do not use a V-bit for the full-depth separation cut.

Do not touch a tool when the spindle can start. Close the machine cover for
each operation. FR-4 dust is harmful. Do not use compressed air. Keep the dust
in the closed machine. Remove it with the vacuum. Clean the board before you
touch your face or food.

The SainSmart quick-start guide supplies a 20-degree V-bit and tells the user
to leave approximately 15 mm of the tool outside the collet. The Cubiko
resource page gives the Genmitsu App and Universal Gcode Sender options. Use
the Genmitsu App for this first panel because its PCB height-map process is
made for the Cubiko.

Sources:

- [Cubiko resource page](https://docs.sainsmart.com/article/8f6ypseduj-cubiko)
- [SainSmart KiCad-to-CNC PCB guide](https://www.sainsmart.com/blogs/news/cubiko-pcb-milling-tutorial)
- [Cubiko product and height-map description](https://genmitsu.com/pages/cubiko)

## Know the repeated-unit layout

The raw blank is nominally 70 mm by 50 mm. The assumed minimum size is 69 mm
by 49 mm. Each unit job uses 70 mm by 24.5 mm nominal coordinates. All copper
and holes have a 0.50 mm shift toward the left. This gives more clearance at
the right edge of a short blank.

Run the first unit from one outside edge. Rotate the complete blank by 180
degrees in its plane. Set X/Y zero at the new lower-left corner. Run the same
file again. The machine file does not contain a second unit or its rotation.
The blank-height error stays between the two units.

The button centers, microphone acoustic center, and buzzer center are on one
straight line. This line is local Y = 12.25 mm on each finished PCB.

Before you mill copper, print `espnoise-component-fit-check.svg` at 100% scale.
Measure the printed 50 mm check line. It must be 50 mm. Put the real MIC1 and
BZ1 parts on the drawing. All leads must align with the hole centers. Update
the measured values in `generate_cnc_board.py`, rebuild the files, and repeat
this check. A screen view is not a physical fit check.

## Know the four coordinates

- Machine zero is the Cubiko home position. Do not change it.
- Work X/Y zero is the lower-left corner of the current blank orientation.
- Work Z zero is the measured copper surface for the installed tool.
- The internal-face job is already mirrored around X = 34.5 mm. This is the
  center of the 69 mm minimum-width reference window.

Each unit run makes one 2.0 mm mounting hole at X = 34.5 mm. Do not use the two
repeated holes as a flip axis when the blank is wider than 69 mm. Use the
corner stops for the copper-face flip. Flip the blank from left to right. Do
not flip it from top to bottom. If the measured blank length is more than
69 mm, put the extra length before X zero on the internal-face presentation.
For example, put 0.8 mm before X zero for a 69.8 mm blank. This keeps the
69 mm reference window aligned on both faces. Make a new Z measurement and a
new height map for each face and after each tool change.

Do not add 70 mm to X after the flip. The generated internal-face G-code
already contains the mirror operation.

## Initial CAM values

The build files use these first-test values:

| Setting | Value |
| --- | ---: |
| Spindle speed | 10,000 RPM |
| Isolation horizontal feed | 120 mm/min |
| Vertical feed | 60 mm/min |
| Isolation depth | 0.05 mm in two equal passes |
| Effective V-bit cut width | 0.20 mm |
| Isolation width | 0.40 mm |
| Safe Z | 2.0 mm |
| Drill depth | 1.8 mm |

The SainSmart PCB guide gives an isolation depth range from 0.01 mm through
0.05 mm. Tests on the installed copper blank gave a cleaner result with two
equal passes to 0.05 mm. Confirm that height compensation is applied. Copper
thickness, tool tip width, spindle runout, and board flatness change the
result.

There is no fixed blank-separation file. Its Y coordinate depends on the
measured blank height. Do not use an old `espnoise-panel-separate.nc` file.

## Make and test the coupon

Run the build script. Use the files that start with `coupon-`.

1. Fix a small FR-4 test piece to the spoilboard with its user face up.
2. Confirm that the clamps are outside the 30 mm by 15 mm job area.
3. Set work X/Y zero at the coupon lower-left corner.
4. Install the 2.0 mm drill. Set Z zero.
5. Run `coupon-drill-2.0mm.nc`.
6. Install the V-bit. Set Z zero. Make a height map for 30 mm by 15 mm.
7. Run `coupon-user-face.nc`.
8. Check that each copper path is continuous and isolated.
9. Put two smooth 2.0 mm pins into the spoilboard holes.
10. Flip the coupon from left to right. Put it on the pins and clamp it.
11. Set Z zero and make a new height map.
12. Run `coupon-internal-face.nc`.
13. Check the front-to-back alignment at the 0.8 mm via holes.
14. Run the 0.8 mm, 0.9 mm, and 1.0 mm drill jobs with the matching drills.
15. Install the 1.0 mm PCB router bit. Set Z zero.
16. Fix both sides of the coupon separation line to the spoilboard.
17. Run `coupon-separate.nc` last.

The coupon cut at Y = 13.5 mm removes a narrow edge strip. Check the cut wall.
It must not have large fibers, burns, or a large burr. Reduce the feed only if
the tool or machine needs it. Stop if the tool bends, chatters, or becomes hot.

Use the multimeter continuity mode. Adjacent copper paths must not connect.
Each complete path must have low resistance. Drill holes must keep the complete
annular ring. The front and back via pads must be concentric.

If copper remains between two paths, first check the height map and the tool
tip. Increase the depth by only 0.01 mm. Do not use an isolation depth below
-0.05 mm for this first test. If a cut is too wide, reduce the depth or use the
smaller-angle V-bit. Change `zwork` or `mill-diameters` in both millproject
files. Then run the build script again.

## Mill two units on one blank

Use a new blank after all coupon checks pass.

1. Measure and record the blank length, height, and thickness. Stop if its
   length is less than 69 mm or its height is less than 49 mm.
2. Mark one face `USER` and mark its lower-left corner.
3. Fix the complete blank with the user face up.
4. Set X/Y zero at the marked lower-left corner.
5. Install the 2.0 mm drill and set Z zero.
6. Run `espnoise-unit-drill-2.0mm.nc`.
7. Install the validated V-bit and set Z zero.
8. Make a height map for the first 69 mm by 24.5 mm reference area.
9. Run `espnoise-unit-user-face.nc`.
10. Check the isolation. Rotate the blank by 180 degrees in its plane.
11. Set X/Y zero at the new lower-left corner. Set Z zero and make a new
    height map for the second unit area.
12. Run `espnoise-unit-drill-2.0mm.nc` and `espnoise-unit-user-face.nc` again.
13. Record the measured blank length. Flip the blank from left to right. Do
    not rotate it in its plane during this face flip. Put it against the corner
    stops.
14. Set X zero inward from the presented left edge by `length - 69.0 mm`.
    Keep Y zero at the presented lower edge. For a 69.0 mm blank, X zero is on
    the edge.
15. Set Z zero, make a new height map, and run
    `espnoise-unit-internal-face.nc`.
16. Rotate the blank by 180 degrees in its plane. Set X/Y zero with the same
    69 mm reference rule. Make a new height map. Run
    `espnoise-unit-internal-face.nc` again.
17. Flip the blank back to the `USER` face. Use the same two user-face
    orientations to run the 0.8 mm, 0.9 mm, 1.0 mm, and 1.2 mm unit drill
    files. Set Z zero after each tool change.
18. Do all electrical checks before you separate the two units.
19. Measure the center space between the two unit areas. Only make a router
    cut if its complete 1.0 mm kerf stays outside both unit areas.
20. Clamp both future parts. Set Z zero and do a safe-Z dry run of a cut that
    uses the measured blank height. Do not use the removed fixed center file.
21. Vacuum the closed machine. Lightly remove edge burrs.
22. Wash the PCBs with isopropyl alcohol and let them dry.

Do not hold a PCB by hand during the separation cut. Do not use only one clamp
for the complete panel. The two free parts can move when the cut finishes. Use
low-profile clamps on both halves, or use strong thin double-face fixture tape
under both halves. Make sure that the tool cannot touch a clamp.

## Electrical check before solder

Do not connect power during these checks.

1. Check each adjacent PWR1, J_ESP32, J_LED, switch, MIC1, and BZ1 pad pair
   for a short circuit.
2. Check `+5V_IN` to GND and `+5V_PERIPH` to GND. Both results must be open.
3. Check each track from one listed endpoint to the other endpoint.
4. Check that each registration hole has no copper contact.
5. Compare diode, transistor, buzzer, and wire-pad marks with the schematic
   and netlist.

Do not repair a narrow gap with a powered rotary tool. Disconnect the board.
Use a fine knife or a small hand tool under magnification.

## Wire vias and solder order

This home-milled board has no plated holes. Install all 0.8 mm wire vias before
you install a component:

1. Put tinned 0.5 mm solid copper wire through each wire-via hole.
2. Solder the wire on both copper faces.
3. Cut the wire close to both solder joints.
4. Check continuity through each via.
5. Check that each via has no short to an adjacent path.

This revision needs no insulated link wires.

Install low parts first. Install the resistors, diode, transistor, and fuse.
Install the insulated wires in PWR1, J_ESP32, and J_LED. Add strain relief to
the wires, but do not cover a pad or a bare copper path. Install the user-face
switches, microphone module, and buzzer last.

Confirm the `2N3904` E-B-C pin order from its data sheet. Confirm the INMP441
module pin labels. Do not install a part only from its seller title.

## First power test

Keep J_ESP32 and J_LED disconnected for the first test. Put SW2 in the
buzzer-off position.

1. Put a current-limited 5 V supply on PWR1.
2. Start with a 100 mA current limit.
3. Confirm 5 V at J_ESP32-1 and after F1 at J_LED-1.
4. Disconnect power. Connect J_ESP32-1 through J_ESP32-7 and J_ESP32-9. Keep
   J_ESP32-8 disconnected.
5. Test the microphone before you connect the LED strip.
6. Test one SK6812 RGBW pixel through J_LED at no more than the present
   brightness limit.
7. Connect all 10 to 12 pixels only after the one-pixel test passes.
8. Connect J_ESP32-8. Test the buzzer driver and its hard switch last.

Keep the external USB-C power input separate from the ESP32 firmware-service
port. Do not power both inputs at the same time. The buzzer switch must stay in
the buzzer power wire.

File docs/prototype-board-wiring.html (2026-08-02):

All wires 5 V GND Microphone Button Buzzer LED output

J1 — microphone and mute cable
Pin | ESP32 | Board destination
1 | 3V3 | INMP441 VDD
2 | GND | Common GND bus
3 | GPIO26 | INMP441 SCK
4 | GPIO25 | INMP441 WS
5 | GPIO32 | INMP441 SD
6 | GPIO27 | Mute button

J2 — output and board power cable
Pin | Connection | Board destination
1 | 5 V rail | 5 V bus
2 | ESP32 GND | Common GND bus
3 | GPIO23 | 5.1 kΩ, then Q1 base
4 | GPIO18 | AHCT pin 2, later

Component connections on the back
Part | Connection 1 | Connection 2 | Other
Bistable switch | 5 V bus | Buzzer + | Hard power switch
Passive buzzer | + from switch | − to Q1 collector | No diode
2N3904 Q1 | Emitter to GND | Collector to buzzer − | Base through 5.1 kΩ to GPIO23
Mute button | One terminal to GND | Other terminal to GPIO27 | Normally open
INMP441 | VDD to 3V3 | GND and L/R to GND | SCK 26 · WS 25 · SD 32

SN74AHCT125N connections — install when the part arrives
Pins | Connection | Purpose
14 | 5 V bus | VCC
7 | GND bus | GND
1 | GND bus | Enable output 1
2 | ESP32 GPIO18 | 3.3 V LED data input
3 | 330 Ω, then LED DIN | 5 V LED data output
4, 10, 13 | 5 V bus | Disable unused outputs
5, 9, 12 | GND bus | Keep unused inputs stable
6, 8, 11 | No connection | Unused outputs
100 nF capacitor | Between pins 14 and 7 | Place close to the IC

Suggested routes are functional, not exact hole coordinates. Verify each component leg with continuity mode before soldering.

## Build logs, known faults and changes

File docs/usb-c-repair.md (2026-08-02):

# USB-C compatibility repair

This is an optional advanced method. The first build uses a separate two-wire
USB-C power module and does not need this board repair.

## Problem

The old ESP32 board operates with a USB-A to USB-C cable but does not operate
with a USB-C to USB-C cable. This usually means that its USB-C socket does not
have the two required configuration-channel pull-down resistors.

A USB-A port supplies 5 V without USB-C attachment detection. A USB-C source
first looks for an `Rd` pull-down on a configuration-channel pin. If it does
not find the pull-down, it keeps VBUS off.

## Preferred board repair

Add two independent 5.1 kohm, 1% resistors:

```text
USB-C receptacle CC1 (A5) ── 5.1 kohm ── board GND
USB-C receptacle CC2 (B5) ── 5.1 kohm ── board GND
```

Do not connect CC1 and CC2 together. Do not use one resistor for both pins.
Do not connect a resistor to D+, D-, SBU1, SBU2, or VBUS.

This is a hardware-only repair. It does not need USB Power Delivery firmware.
It keeps the original USB-C port for power, firmware upload, and the serial
monitor.

## Parts

- 2 resistors, 5.1 kohm, 1%, 0603 or 0805 SMD
- Fine insulated wire, 30 AWG, only if a resistor cannot connect directly
- Fine soldering tip, flux, magnification, and a multimeter

Select the resistor size only after inspection of the board. The USB-C contact
pitch is small. Do not attempt the repair without a clear view of the pads.

## Inspection before soldering

1. Disconnect all USB power and all modules.
2. Identify the exact USB-C receptacle or follow its CC traces.
3. Identify CC1 and CC2 from the connector data sheet or board traces. Do not
   use a generic pad position without confirmation.
4. Confirm that CC1 and CC2 are not shorted together.
5. Measure from each CC pin to board GND.
6. If both values are already near 5.1 kohm, do not add more resistors. The
   fault has a different cause.
7. If the pins are open to GND, install the two resistors.

If CC1 and CC2 are shorted together, stop. The traces must be separated before
the two resistors can be installed. A full-data adapter module is safer in
that condition.

## Test after soldering

1. Use magnification to look for solder bridges.
2. With power disconnected, measure approximately 5.1 kohm from CC1 to GND.
3. Measure approximately 5.1 kohm from CC2 to GND.
4. Confirm that VBUS is not shorted to GND, CC1, or CC2.
5. Connect a USB-C to USB-C cable with no external modules connected.
6. Measure 4.75 V to 5.25 V from the board `5V` or `VIN` pin to GND.
7. Reverse the cable plug and repeat the power test.
8. Confirm serial-port detection and firmware upload in both plug positions.
9. Connect the microphone.
10. Connect one LED pixel, and then the complete sign.

Disconnect the LED power plug during the first firmware-upload tests. A
computer USB port can advertise less current than a wall supply.

## Use of a two-wire USB-C connector

A two-wire connector exposes only VBUS and GND. It cannot carry D+ and D-, so
it cannot upload firmware or provide a serial monitor.

Some two-wire USB-C boards include the two 5.1 kohm resistors. Some do not. A
board without them has the same USB-C to USB-C power fault.

Use a two-wire connector only for a separate power-only test or a later power
module. Do not use it for the preferred single-port build.

## Full-data adapter fallback

If the board CC pads are not accessible, use a USB 2.0 Type-C female breakout
that has all of these connections:

- VBUS and GND
- D+ and D-
- Separate CC1 and CC2 pads
- One 5.1 kohm pull-down from each CC pad to GND

Connect this module through a short full-data cable to the ESP32 USB-C port.
This keeps one external connector for power and upload, but it uses more space
than the direct board repair. A two-wire breakout is not a valid substitute.

## Technical sources

- [USB Type-C Cable and Connector Specification](https://www.usb.org/sites/default/files/USB%20Type-C%20Spec%20R2.0%20-%20August%202019.pdf)
- [Microchip USB-C downstream-device example](https://onlinedocs.microchip.com/oxy/GUID-D5B5915F-6907-409C-A6D9-F79690ACDCA3-en-US-1/GUID-EBF2E2A2-E9F3-4834-B185-F9FCCCABB46F.html)

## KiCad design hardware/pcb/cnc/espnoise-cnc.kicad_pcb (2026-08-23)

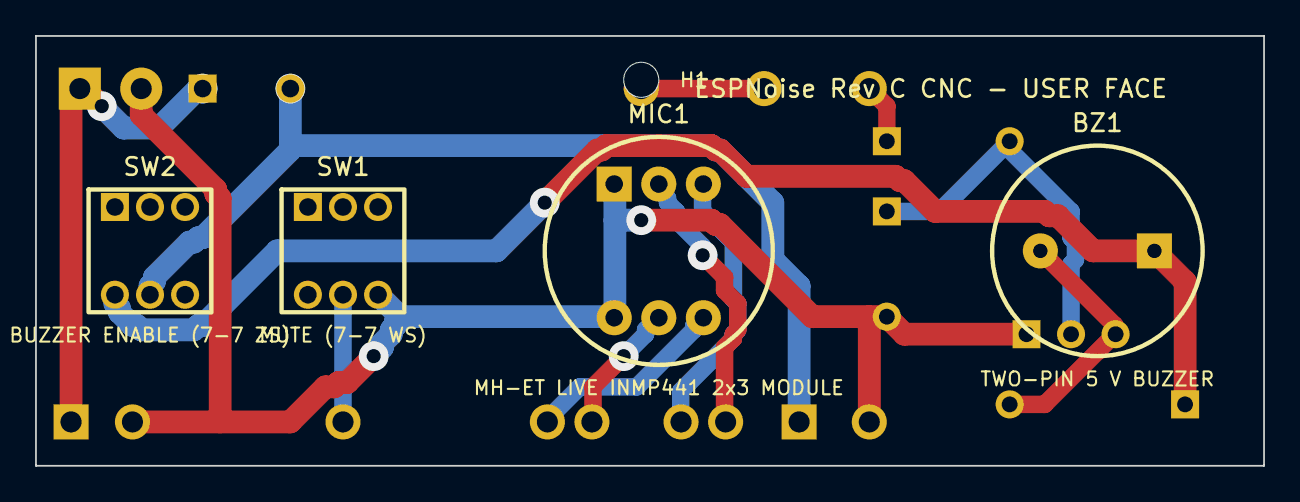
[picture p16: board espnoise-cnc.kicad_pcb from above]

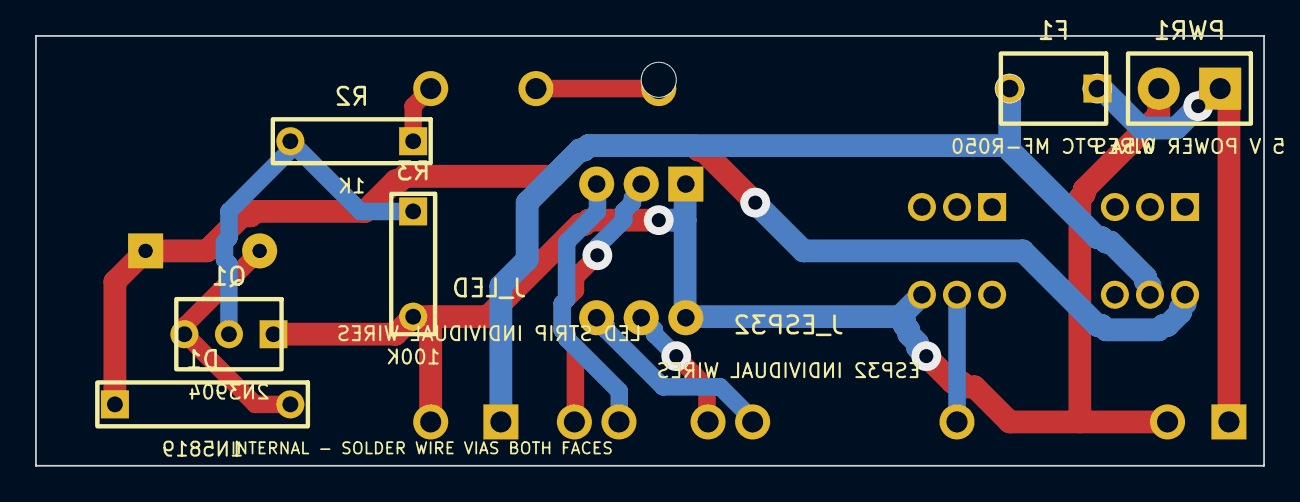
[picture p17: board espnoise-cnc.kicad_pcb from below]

Board: 2 copper layers, 70.0 x 24.5 mm, 13 parts (8 on the bottom side), 13 nets.

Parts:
BZ1: TWO-PIN 5 V BUZZER; Buzzer_THT_2Pin_P6.50mm_D12mm
D1: 1N5819; Axial
F1: 0.5A PTC MF-R050; Fuse_Radial_P5.00mm
H1: RegistrationHole_2mm
J_ESP32: ESP32 INDIVIDUAL WIRES; IndividualWireGroup_ESP32
J_LED: LED STRIP INDIVIDUAL WIRES; IndividualWireGroup_LED
MIC1: MH-ET LIVE INMP441 2x3 MODULE; MH_ET_LIVE_INMP441_2x3_P2.54_Row7.62
PWR1: 5 V POWER WIRES; WirePads_2_P3.5mm
Q1: 2N3904; TO-92_Inline_EBC
R2: 1K; Axial
R3: 100K; Axial
SW1: MUTE (7-7 WS); 7x7_DPDT_Pushbutton
SW2: BUZZER ENABLE (7-7 ZS); 7x7_DPDT_Pushbutton

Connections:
+3V3: J_ESP32.3, MIC1.2
+5V_BUZZER_SW: BZ1.1, D1.1, SW2.4
+5V_IN: F1.1, J_ESP32.1, PWR1.1
+5V_PERIPH: F1.2, J_LED.1, SW2.5
BUZZER_BASE: Q1.2, R2.2, R3.1
BUZZER_COLLECTOR: BZ1.2, D1.2, Q1.3
BUZZER_PWM: J_ESP32.8, R2.1
GND: J_ESP32.2, J_LED.3, MIC1.1, MIC1.4, PWR1.2, Q1.1, R3.2, SW1.6
LED_DATA: J_ESP32.7, J_LED.2
MIC_SCK: J_ESP32.4, MIC1.6
MIC_SD: J_ESP32.6, MIC1.3
MIC_WS: J_ESP32.5, MIC1.5
MUTE_N: J_ESP32.9, SW1.5

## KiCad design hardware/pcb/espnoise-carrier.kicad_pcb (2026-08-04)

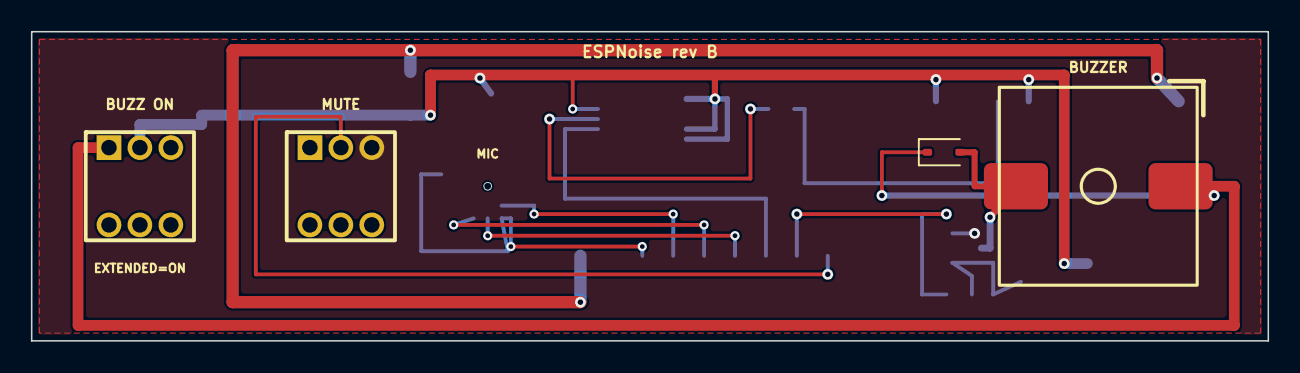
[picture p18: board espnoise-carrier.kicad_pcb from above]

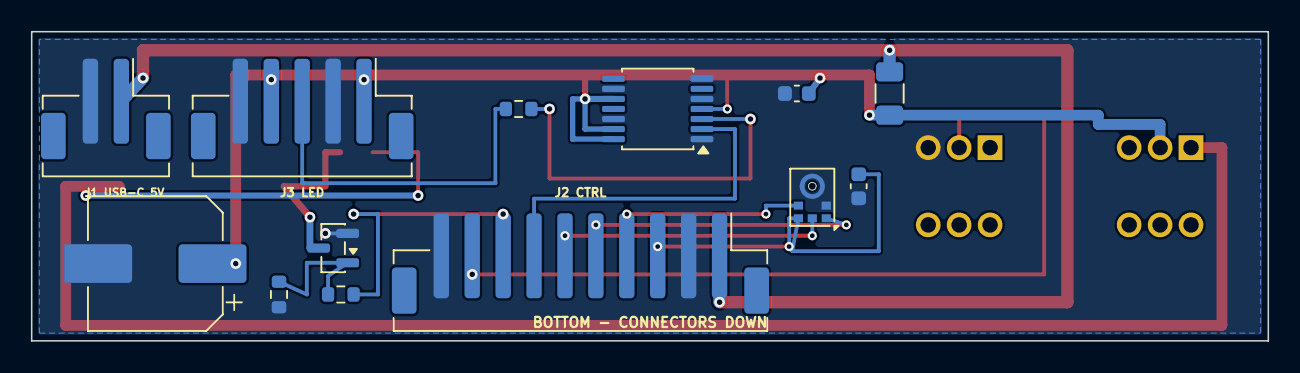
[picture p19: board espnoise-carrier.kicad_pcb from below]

Board: 2 copper layers, 80.0 x 20.0 mm, 17 parts (13 on the bottom side), 15 nets.

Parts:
BZ1: FUET-1370F-05; ESPNoise_FUET-1370F-05
C1, C3: 100nF; C_0603_1608Metric
C2: 1000uF 10V; CP_Elec_8x10.5
D1: 1N5819WS; D_SOD-323
F1: 0.5A PTC; Fuse_1206_3216Metric
J1: USB-C 5V; JST_PH_B2B-PH-SM4-TB_1x02-1MP_P2.00mm_Vertical
J2: CONTROLLER; JST_PH_B10B-PH-SM4-TB_1x10-1MP_P2.00mm_Vertical
J3: LED STRIP; JST_PH_B5B-PH-SM4-TB_1x05-1MP_P2.00mm_Vertical
MIC1: ICS-43434; InvenSense_ICS-43434-6_3.5x2.65mm
Q1: MMBT3904; SOT-23
R1: 330R; R_0603_1608Metric
R2: 1k; R_0603_1608Metric
R3: 100k; R_0603_1608Metric
SW1: MUTE; ESPNoise_7x7_DPDT_Pushbutton
SW2: BUZZER ENABLE; ESPNoise_7x7_DPDT_Pushbutton
U1: SN74AHCT125PWR; TSSOP-14_4.4x5mm_P0.65mm

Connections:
+3V3: C3.1, J2.3, MIC1.5
+5V_BUZZER_SW: BZ1.1, D1.1, SW2.1
+5V_IN: F1.1, J1.1, J2.1
+5V_PERIPH: C1.1, C2.1, F1.2, J3.1, J3.4, SW2.2, U1.4, U1.10, U1.13, U1.14
BUZZER_BASE: Q1.1, R2.2, R3.1
BUZZER_COLLECTOR: BZ1.2, D1.2, Q1.3
BUZZER_PWM: J2.8, R2.1
GND: C1.2, C2.2, C3.2, J1.2, J2.2, J2.10, J3.2, J3.5, MIC1.2, MIC1.3, Q1.2, R3.2, SW1.3, U1.1, U1.5, U1.7, U1.9, U1.12
LED_DATA_3V3: J2.7, U1.2
LED_DATA_5V: J3.3, R1.2
LED_DATA_5V_RAW: R1.1, U1.3
MIC_SCK: J2.4, MIC1.4
MIC_SD: J2.6, MIC1.6
MIC_WS: J2.5, MIC1.1
MUTE_N: J2.9, SW1.2

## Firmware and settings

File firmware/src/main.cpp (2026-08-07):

#include <Arduino.h>
#include <WiFi.h>
#include <esp_bt.h>
#include <esp_system.h>

#include <algorithm>
#include <cmath>

#include "alarm_output.h"
#include "audio_input.h"
#include "ble_service.h"
#include "board_profile.h"
#include "config_packet.h"
#include "config.h"
#include "device_name.h"
#include "mute_button.h"
#include "mute_state.h"
#include "noise_detector.h"
#include "noise_analytics.h"
#include "settings_storage.h"

namespace {

AudioInput audioInput;
NoiseDetector noiseDetector;
noise_analytics::History analyticsHistory;
MuteButton muteButton;
MuteState muteState;
RuntimeSettings runtimeSettings;
config_packet::Bytes appliedPacket{};
device_name::Value appliedDeviceName;
uint32_t appliedRevision = 0;

float currentDbfs = -120.0F;
bool sampleActive = false;
bool alarmActive = false;
AlarmLevel currentAlarmLevel = AlarmLevel::kQuiet;
uint32_t sampleStartMs = 0;
uint32_t currentSampleDurationMs = config::kSampleDurationMs;
uint32_t nextSampleStartMs = 0;
uint32_t alarmStartMs = 0;
uint32_t alarmPatternStartMs = 0;
uint32_t lastLevelPrintMs = 0;
uint8_t settingsErrorCode = 0;
uint16_t measurementSequence = 0;
uint32_t lastAnalyticsSecondMs = 0;
uint32_t lastAnalyticsNotifyMs = 0;
uint32_t analyticsAfterSequence = 0;
size_t analyticsSyncCursor = 0;
bool analyticsCurrentIsPending = false;
bool analyticsSyncIsActive = false;
bool bluetoothEnabled = true;

device_name::Value defaultDeviceName() {
  device_name::Value name;
  char text[19] = {};
  const uint64_t chipId = ESP.getEfuseMac();
  const int length = snprintf(text, sizeof(text), "Device %04X",
                              static_cast<unsigned>(chipId & 0xFFFFU));
  name.length = static_cast<uint8_t>(std::max(0, length));
  std::copy(text, text + name.length, name.bytes.begin());
  return name;
}

bool timeIsDue(uint32_t now, uint32_t target) {
  return static_cast<int32_t>(now - target) >= 0;
}

bool isMuted(uint32_t now) {
  return muteState.isMuted(now);
}

const char* levelName(AlarmLevel level) {
  if (level == AlarmLevel::kRed) {
    return "red";
  }
  if (level == AlarmLevel::kOrange) {
    return "orange";
  }
  if (level == AlarmLevel::kGreen) {
    return "green";
  }
  return "quiet";
}

void printActiveSettings() {
  Serial.printf(
      "Settings active: green=%.1f orange=%.1f red=%.1f dBFS "
      "K=%lu ms N=%lu ms window=%lu ms X=%u%% required=%u/%u\n",
      runtimeSettings.greenThresholdDbfsX10 / 10.0F,
      runtimeSettings.orangeThresholdDbfsX10 / 10.0F,
      runtimeSettings.redThresholdDbfsX10 / 10.0F,
      static_cast<unsigned long>(runtimeSettings.sampleDurationMs),
      static_cast<unsigned long>(runtimeSettings.samplePeriodMs),
      static_cast<unsigned long>(runtimeSettings.decisionWindowMs),
      static_cast<unsigned>(runtimeSettings.triggerSamplePercent),
      static_cast<unsigned>(runtimeSettings.requiredTriggerSampleCount()),
      static_cast<unsigned>(runtimeSettings.historySampleCount()));
}

void failMicrophone() {
  Serial.println("ERROR: I2S microphone start failed");
  audioInput.stop();
  while (true) {
    alarm_output::showMicrophoneError(true);
    delay(250);
    alarm_output::showMicrophoneError(false);
    delay(250);
  }
}

void beginSample(uint32_t now) {
  (void)now;
  if (!alarmActive) {
    alarm_output::off();
  }
  alarm_output::silenceBuzzer();
  if (!audioInput.start()) {
    failMicrophone();
  }

  noiseDetector.beginSample();
  currentDbfs = -120.0F;
  sampleStartMs = millis();
  currentSampleDurationMs =
      alarmActive ? config::kAlarmActiveSampleDurationMs
                  : runtimeSettings.sampleDurationMs;
  sampleActive = true;
  Serial.println(alarmActive ? "Alarm observation started"
                             : "Observation started");
}

void endSample(uint32_t now) {
  audioInput.stop();
  sampleActive = false;

  const bool alarmWasActive = alarmActive;
  noiseDetector.commitSample();
  const AlarmLevel historyLevel = noiseDetector.historyAlarmLevel();
  if (historyLevel != AlarmLevel::kQuiet && !isMuted(now)) {
    alarmActive = true;
    currentAlarmLevel = historyLevel;
    if (!alarmWasActive) {
      alarmStartMs = now;
    }
    alarmPatternStartMs = now;
    nextSampleStartMs = now + config::kAlarmOutputWindowMs +
                        config::kBuzzerSettleMs;
  } else {
    alarmActive = false;
    currentAlarmLevel = isMuted(now) ? historyLevel : AlarmLevel::kQuiet;
    alarmStartMs = 0;
    alarmPatternStartMs = 0;
    nextSampleStartMs = sampleStartMs + runtimeSettings.samplePeriodMs;
    if (timeIsDue(now, nextSampleStartMs)) {
      nextSampleStartMs = now;
    }
  }

  Serial.printf(
      "%s ended: max=%.1f dBFS history=%u/%u green=%.1f%% "
      "orange=%.1f%% red=%.1f%% alarm=%s level=%s\n",
      alarmWasActive ? "Alarm observation" : "Observation",
      noiseDetector.sampleMaximumDbfs(),
      static_cast<unsigned>(noiseDetector.historyCount()),
      static_cast<unsigned>(runtimeSettings.historySampleCount()),
      noiseDetector.greenSampleRatio() * 100.0F,
      noiseDetector.orangeSampleRatio() * 100.0F,
      noiseDetector.redSampleRatio() * 100.0F, alarmActive ? "on" : "off",
      levelName(currentAlarmLevel));
}

void resumeAlarmFromHistory(uint32_t now) {
  const AlarmLevel historyLevel = noiseDetector.historyAlarmLevel();
  currentAlarmLevel = historyLevel;
  if (historyLevel == AlarmLevel::kQuiet) {
    alarmActive = false;
    alarmStartMs = 0;
    alarmPatternStartMs = 0;
    return;
  }
  alarmActive = true;
  alarmStartMs = now;
  alarmPatternStartMs = now;
  nextSampleStartMs = now + config::kAlarmOutputWindowMs +
                      config::kBuzzerSettleMs;
}

void updateMute(uint32_t now) {
  const MuteButtonEvent event = muteButton.update(now);
  if (event == MuteButtonEvent::kLongPress) {
    const bool candidate = !bluetoothEnabled;
    if (!settings_storage::saveBluetoothEnabled(candidate)) {
      Serial.println("ERROR: Bluetooth state save failed; change rejected");
    } else if (candidate) {
      bluetoothEnabled = true;
      if (ble_service::begin(appliedPacket, appliedDeviceName)) {
        alarm_output::startBluetoothTransition(millis(), true);
        Serial.println("Bluetooth enabled by button hold");
      } else {
        bluetoothEnabled = false;
        settings_storage::saveBluetoothEnabled(false);
        Serial.println("ERROR: Bluetooth enable rejected");
      }
    } else {
      analyticsSyncIsActive = false;
      if (ble_service::end()) {
        bluetoothEnabled = false;
        alarm_output::startBluetoothTransition(millis(), false);
        Serial.println("Bluetooth disabled by button hold");
      } else {
        settings_storage::saveBluetoothEnabled(true);
        Serial.println("ERROR: Bluetooth disable rejected");
      }
    }
  } else if (event == MuteButtonEvent::kShortPress) {
    const bool alarmWasActive = alarmActive;
    const MutePressResult result =
        muteState.press(now, runtimeSettings.muteDurationSeconds);
    if (result == MutePressResult::kUnmuted) {
      resumeAlarmFromHistory(now);
      Serial.println("Mute ended by double press");
      return;
    }

    alarmActive = false;
    currentAlarmLevel = AlarmLevel::kQuiet;
    alarmStartMs = 0;
    alarmPatternStartMs = 0;
    if (sampleActive) {
      currentSampleDurationMs = runtimeSettings.sampleDurationMs;
    } else if (alarmWasActive) {
      nextSampleStartMs = now;
    }
    alarm_output::off();
    Serial.printf(
        result == MutePressResult::kMuteExtended
            ? "Mute restarted for %lu seconds\n"
            : "Muted for %lu seconds\n",
        static_cast<unsigned long>(runtimeSettings.muteDurationSeconds));
  }

  if (muteState.update(now)) {
    resumeAlarmFromHistory(now);
    Serial.println("Mute ended");
  }
}

ble_service::Status makeBleStatus(uint32_t now) {
  ble_service::Status status;
  status.alarmState = static_cast<uint8_t>(currentAlarmLevel);
  status.muted = isMuted(now);
  status.sampling = sampleActive;
  status.alarmActive = alarmActive;
  status.errorCode = settingsErrorCode;
  status.appliedRevision = appliedRevision;
  status.fingerprint = config_packet::fingerprint(appliedPacket);
  status.measurementValid = noiseDetector.frameCount() > 0;
  const float maximumDbfs = std::max(
      -120.0F, std::min(0.0F, noiseDetector.sampleMaximumDbfs()));
  status.observationMaximumDbfsX10 =
      static_cast<int16_t>(std::lround(maximumDbfs * 10.0F));
  status.measurementSequence = measurementSequence;
  status.historyCount = static_cast<uint8_t>(noiseDetector.historyCount());
  status.greenSampleCount =
      static_cast<uint8_t>(noiseDetector.greenSampleCount());
  status.orangeSampleCount =
      static_cast<uint8_t>(noiseDetector.orangeSampleCount());
  status.redSampleCount =
      static_cast<uint8_t>(noiseDetector.redSampleCount());
  return status;
}

void clearRuntimeState(uint32_t now) {
  alarmActive = false;
  currentAlarmLevel = AlarmLevel::kQuiet;
  alarmStartMs = 0;
  alarmPatternStartMs = 0;
  noiseDetector.resetHistory();
  alarm_output::off();
  nextSampleStartMs = now;
}

void applyPendingSettings(uint32_t now) {
  if (sampleActive) {
    return;
  }

  config_packet::Bytes candidate{};
  RuntimeSettings candidateSettings;
  uint32_t candidateRevision = 0;
  if (!ble_service::takePending(candidate, candidateSettings,
                                candidateRevision)) {
    return;
  }

  const bool packetChanged = candidate != appliedPacket;
  const bool analyticsWillBeDisabled =
      runtimeSettings.analyticsEnabled && !candidateSettings.analyticsEnabled;
  if (analyticsWillBeDisabled && !settings_storage::clearAnalytics()) {
    Serial.println("ERROR: Analytics erase failed; update rejected");
    settingsErrorCode = 1;
    ble_service::acknowledge(appliedPacket, makeBleStatus(now));
    return;
  }
  if (packetChanged && !settings_storage::save(candidate)) {
    Serial.println("ERROR: Settings save failed; update rejected");
    settingsErrorCode = 1;
    ble_service::Status status = makeBleStatus(now);
    ble_service::acknowledge(appliedPacket, status);
    return;
  }

  settingsErrorCode = 0;
  runtimeSettings = candidateSettings;
  appliedPacket = candidate;
  appliedRevision = candidateRevision;
  noiseDetector.setSettings(runtimeSettings);
  alarm_output::setSettings(runtimeSettings);
  if (analyticsWillBeDisabled) {
    analyticsHistory = noise_analytics::History{};
    analyticsSyncIsActive = false;
    lastAnalyticsSecondMs = now;
    Serial.println("Analytics collection disabled and saved history erased");
  }
  clearRuntimeState(now);
  ble_service::acknowledge(appliedPacket, makeBleStatus(now));
  Serial.printf("Settings applied: revision=%lu fingerprint=%08lX\n",
                static_cast<unsigned long>(appliedRevision),
                static_cast<unsigned long>(
                    config_packet::fingerprint(appliedPacket)));
  printActiveSettings();
}

void applyPendingName() {
  if (sampleActive) {
    return;
  }
  device_name::Value candidate;
  if (!ble_service::takePendingName(candidate)) {
    return;
  }
  if (candidate != appliedDeviceName &&
      !settings_storage::saveName(candidate)) {
    Serial.println("ERROR: Device name save failed; update rejected");
    ble_service::acknowledgeName(appliedDeviceName);
    return;
  }
  appliedDeviceName = candidate;
  ble_service::acknowledgeName(appliedDeviceName);
  Serial.println("Device name applied");
}

void answerNameReadRequest() {
  if (ble_service::takeNameReadRequest()) {
    ble_service::notifyName(appliedDeviceName);
  }
}

void updateAnalytics(uint32_t now) {
  if (!runtimeSettings.analyticsEnabled) {
    lastAnalyticsSecondMs = now;
    return;
  }
  while (now - lastAnalyticsSecondMs >= 1000) {
    lastAnalyticsSecondMs += 1000;
    const float maximumDbfs = std::max(
        -120.0F, std::min(0.0F, noiseDetector.sampleMaximumDbfs()));
    analyticsHistory.addSecond(
        currentAlarmLevel,
        static_cast<int16_t>(std::lround(maximumDbfs * 10.0F)),
        noiseDetector.frameCount() > 0);
  }

  if (!sampleActive && analyticsHistory.persistenceIsDue()) {
    if (settings_storage::saveAnalytics(analyticsHistory)) {
      analyticsHistory.markPersisted();
      Serial.println("Analytics history saved");
    } else {
      Serial.println("ERROR: Analytics history save failed");
    }
  }
  if (analyticsHistory.sequencePersistenceIsDue()) {
    if (settings_storage::saveAnalyticsSequence(
            analyticsHistory.currentSequence())) {
      analyticsHistory.markSequencePersisted();
    } else {
      Serial.println("ERROR: Analytics sequence save failed");
    }
  }
}

void updateAnalyticsSync(uint32_t now) {
  if (!runtimeSettings.analyticsEnabled) {
    uint32_t unusedAfterSequence = 0;
    uint32_t unusedUtcSeconds = 0;
    ble_service::takeAnalyticsRequest(unusedAfterSequence,
                                      unusedUtcSeconds);
    analyticsSyncIsActive = false;
    return;
  }
  uint32_t requestedAfterSequence = 0;
  uint32_t currentUtcSeconds = 0;
  if (ble_service::takeAnalyticsRequest(requestedAfterSequence,
                                        currentUtcSeconds)) {
    if (!analyticsHistory.syncUtcTime(currentUtcSeconds)) {
      Serial.println("ERROR: Analytics UTC time is invalid");
      return;
    }
    analyticsAfterSequence = requestedAfterSequence;
    analyticsSyncCursor = 0;
    analyticsCurrentIsPending = true;
    analyticsSyncIsActive = true;
    Serial.printf("Analytics sync requested: after=%lu utc=%lu\n",
                  static_cast<unsigned long>(requestedAfterSequence),
                  static_cast<unsigned long>(currentUtcSeconds));
  }
  if (!analyticsSyncIsActive || now - lastAnalyticsNotifyMs < 60) {
    return;
  }

  if (analyticsCurrentIsPending) {
    if (ble_service::notifyAnalytics(analyticsHistory.currentPacket())) {
      analyticsCurrentIsPending = false;
      lastAnalyticsNotifyMs = now;
    }
    return;
  }

  noise_analytics::Bucket bucket;
  while (analyticsSyncCursor < analyticsHistory.recordCount()) {
    if (!analyticsHistory.recordAt(analyticsSyncCursor++, bucket) ||
        !noise_analytics::History::sequenceIsAfter(
            bucket.sequence, analyticsAfterSequence)) {
      continue;
    }
    if (ble_service::notifyAnalytics(analyticsHistory.packetFor(bucket))) {
      lastAnalyticsNotifyMs = now;
    } else {
      --analyticsSyncCursor;
    }
    return;
  }
  analyticsSyncIsActive = false;
}

}  // namespace

void setup() {
  Serial.begin(115200);
  delay(300);
  Serial.printf("Reset reason=%d\n", static_cast<int>(esp_reset_reason()));

  WiFi.mode(WIFI_OFF);
  esp_bt_controller_mem_release(ESP_BT_MODE_CLASSIC_BT);

  appliedPacket = config_packet::encode(runtimeSettings, 0);
  appliedDeviceName = defaultDeviceName();
  const bool storageReady = settings_storage::begin();
  if (!storageReady) {
    Serial.println("ERROR: Settings storage start failed; defaults active");
  } else {
    if (!settings_storage::load(appliedPacket)) {
      appliedPacket = config_packet::encode(runtimeSettings, 0);
      Serial.println("Saved settings are absent or invalid; defaults active");
    }
    if (!settings_storage::loadName(appliedDeviceName)) {
      appliedDeviceName = defaultDeviceName();
    }
    settings_storage::loadBluetoothEnabled(bluetoothEnabled);
  }
  if (config_packet::decode(appliedPacket.data(), appliedPacket.size(),
                            runtimeSettings, appliedRevision) !=
      config_packet::ValidationResult::kValid) {
    runtimeSettings = RuntimeSettings{};
    appliedRevision = 0;
    appliedPacket = config_packet::encode(runtimeSettings, appliedRevision);
  }
  if (storageReady) {
    if (runtimeSettings.analyticsEnabled) {
      if (!settings_storage::loadAnalytics(analyticsHistory)) {
        Serial.println("Saved analytics history is absent or invalid");
      }
    } else if (!settings_storage::clearAnalytics()) {
      Serial.println("ERROR: Disabled analytics history erase failed");
    }
  }

  if (config::kSampleDurationMs == 0 ||
      config::kSampleDurationMs > config::kSamplePeriodMs ||
      config::kTriggerSampleRatio < 0.0F ||
      config::kTriggerSampleRatio > 1.0F ||
      config::kHistorySampleCount == 0 ||
      config::kMinimumHistorySamples == 0 ||
      config::kMinimumHistorySamples > config::kHistorySampleCount ||
      config::kAlarmActiveSampleDurationMs == 0 ||
      config::kGreenThresholdDbfsX10 >=
          config::kOrangeThresholdDbfsX10 ||
      config::kOrangeThresholdDbfsX10 >= config::kRedThresholdDbfsX10 ||
      config::buzzerPatternDurationMs(config::kOrangeStyle) >
          config::kAlarmOutputWindowMs ||
      config::buzzerPatternDurationMs(config::kRedStyle) >
          config::kAlarmOutputWindowMs) {
    Serial.println("ERROR: Invalid sample settings");
    while (true) {
      delay(1000);
    }
  }

  muteButton.begin();
  noiseDetector.setSettings(runtimeSettings);
  alarm_output::setSettings(runtimeSettings);
  alarm_output::begin();
  if (bluetoothEnabled) {
    if (!ble_service::begin(appliedPacket, appliedDeviceName)) {
      bluetoothEnabled = false;
    }
  } else {
    Serial.println("Bluetooth stays disabled from saved state");
  }
  nextSampleStartMs = millis();
  lastAnalyticsSecondMs = nextSampleStartMs;
  printActiveSettings();
  Serial.println("ESPNoise started");
}

void loop() {
  uint32_t now = millis();
  if (bluetoothEnabled) {
    ble_service::update(now);
  }
  updateMute(now);
  if (bluetoothEnabled) {
    answerNameReadRequest();
    applyPendingName();
    applyPendingSettings(now);
  }

  if (!sampleActive && timeIsDue(now, nextSampleStartMs)) {
    beginSample(now);
  }

  if (sampleActive && audioInput.readFrame(currentDbfs)) {
    noiseDetector.addFrame(currentDbfs);
    ++measurementSequence;
  }

  now = millis();
  if (sampleActive && now - sampleStartMs >= currentSampleDurationMs) {
    endSample(now);
  }

  const uint32_t alarmAgeMs = alarmActive ? now - alarmStartMs : 0;
  const uint32_t patternAgeMs = alarmActive ? now - alarmPatternStartMs : 0;
  alarm_output::update(now, alarmActive, sampleActive, isMuted(now),
                       currentAlarmLevel, alarmAgeMs, patternAgeMs);

  if (sampleActive && now - lastLevelPrintMs >= 1000) {
    lastLevelPrintMs = now;
    Serial.printf("level=%.1f dBFS max=%.1f dBFS frames=%u mute=%s\n",
                  currentDbfs, noiseDetector.sampleMaximumDbfs(),
                  static_cast<unsigned>(noiseDetector.frameCount()),
                  isMuted(now) ? "on" : "off");
  }

  if (bluetoothEnabled) {
    ble_service::setStatus(makeBleStatus(now));
  }
  updateAnalytics(now);
  if (bluetoothEnabled) {
    updateAnalyticsSync(now);
  }

  // Let the BLE and Arduino tasks run. NimBLE manages its radio sleep.
  delay(1);
}

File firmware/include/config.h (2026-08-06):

#pragma once

#include <cstddef>
#include <cstdint>

#ifndef ESPNOISE_SAMPLE_DURATION_MS
#define ESPNOISE_SAMPLE_DURATION_MS (1UL * 1000UL)
#endif

#ifndef ESPNOISE_SAMPLE_PERIOD_MS
#define ESPNOISE_SAMPLE_PERIOD_MS (10UL * 1000UL)
#endif

#ifndef ESPNOISE_TRIGGER_SAMPLE_PERCENT
#define ESPNOISE_TRIGGER_SAMPLE_PERCENT 50
#endif

#ifndef ESPNOISE_DECISION_WINDOW_MS
#define ESPNOISE_DECISION_WINDOW_MS (60UL * 1000UL)
#endif

#ifndef ESPNOISE_LED_BRIGHTNESS
#define ESPNOISE_LED_BRIGHTNESS 64
#endif

namespace config {

struct AlarmStyle {
  uint8_t red;
  uint8_t green;
  uint8_t blue;
  uint8_t warmWhite;
  uint32_t blinkHalfPeriodMs;
  uint32_t buzzerFrequencyHz;
  uint16_t buzzerPulseMs;
  uint16_t buzzerGapMs;
  uint8_t buzzerPulseCount;
};

constexpr uint32_t buzzerPatternDurationMs(const AlarmStyle& style) {
  return style.buzzerPulseCount == 0
             ? 0
             : style.buzzerPulseCount * style.buzzerPulseMs +
                   (style.buzzerPulseCount - 1) * style.buzzerGapMs;
}

// Sign output.
constexpr uint8_t kLedCount = 10;
// This is the board power limit. Runtime brightness is a percentage of this
// value. Keep the battery board at or below 25% until a power test permits a
// higher value.
constexpr uint8_t kLedBrightnessMaximum = ESPNOISE_LED_BRIGHTNESS;
constexpr uint8_t kDefaultLedBrightnessPercent = 100;

// Audio and decision values. Levels are dBFS until the microphone is
// calibrated against a sound level meter.
constexpr uint32_t kSampleRateHz = 16000;
constexpr int16_t kGreenThresholdDbfsX10 = -550;
constexpr int16_t kOrangeThresholdDbfsX10 = -480;
constexpr int16_t kRedThresholdDbfsX10 = -420;
constexpr float kDcBlockFactor = 0.995F;
constexpr size_t kAudioBlockSamples = 256;
// Ignore microphone startup data after the I2S clock starts. This prevents a
// wake transient from becoming the maximum value of an observation.
constexpr uint32_t kMicrophoneWarmupMs = 300;

// Listen for K seconds in each N-second period. Save the maximum frame level
// from each K-second observation. Start the alarm when at least X percent of
// the saved observations in the decision window reach a level threshold.
constexpr uint32_t kSampleDurationMs = ESPNOISE_SAMPLE_DURATION_MS;  // K
constexpr uint32_t kSamplePeriodMs = ESPNOISE_SAMPLE_PERIOD_MS;      // N
constexpr uint32_t kDecisionWindowMs = ESPNOISE_DECISION_WINDOW_MS;
static_assert(kSamplePeriodMs > 0, "The sample period must be greater than 0");
static_assert(kDecisionWindowMs >= kSamplePeriodMs,
              "The decision window must contain at least one sample period");
static_assert(kDecisionWindowMs % kSamplePeriodMs == 0,
              "The decision window must be a multiple of the sample period");

constexpr float kTriggerSampleRatio =
    static_cast<float>(ESPNOISE_TRIGGER_SAMPLE_PERCENT) / 100.0F;     // X
constexpr size_t kHistorySampleCount =
    kDecisionWindowMs / kSamplePeriodMs;
constexpr size_t kMinimumHistorySamples = kHistorySampleCount;
static_assert(kHistorySampleCount > 0,
              "The decision history must contain at least one observation");

// Active alarms make frequent observations. Each observation replaces the
// oldest value in the same rolling history that controls the output level.
constexpr uint32_t kAlarmActiveSampleDurationMs = 1000;
constexpr uint32_t kAlarmOutputWindowMs = 250;
constexpr uint32_t kBuzzerSettleMs = 100;

// Runtime setting limits. The history allocation is fixed so that a phone
// cannot cause a dynamic allocation in the detector.
constexpr int16_t kMinimumThresholdDbfsX10 = -1200;
constexpr int16_t kMaximumThresholdDbfsX10 = 0;
constexpr size_t kMaximumHistorySampleCount = 120;
constexpr uint8_t kMinimumTriggerSamplePercent = 1;
constexpr uint8_t kMaximumTriggerSamplePercent = 99;
constexpr uint32_t kMinimumMuteDurationSeconds = 60;
constexpr uint32_t kMaximumMuteDurationSeconds = 24UL * 60UL * 60UL;

// User controls.
constexpr uint32_t kDefaultMuteDurationSeconds = 30UL * 60UL;
constexpr uint32_t kButtonDebounceMs = 35;
constexpr uint32_t kBluetoothButtonHoldMs = 2UL * 1000UL;
constexpr uint32_t kBluetoothLightTransitionMs = 2UL * 1000UL;
constexpr uint32_t kMuteDoublePressWindowMs = 750;

// Alarm outputs.
constexpr bool kBuzzerEnabled = true;
constexpr uint8_t kBuzzerVolumePercent = 50;
constexpr uint32_t kPeripheralPowerWarmupMs = 5;

// Light and buzzer styles. Green is light only. Orange gives two warning
// notes. Red gives three faster, higher notes.
constexpr AlarmStyle kGreenStyle = {
    0, 255, 0, 0, 500, 900, 0, 0, 0,
};
constexpr AlarmStyle kOrangeStyle = {
    255, 50, 0, 0, 300, 1500, 70, 55, 2,
};
constexpr AlarmStyle kRedStyle = {
    255, 0, 0, 24, 150, 2400, 50, 35, 3,
};

}  // namespace config

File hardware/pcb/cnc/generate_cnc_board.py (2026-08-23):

#!/usr/bin/env python3
"""Generate the ESPNoise Rev C CNC unit.

The generated files do not need KiCad. KiCad can open the generated board, and
pcb2gcode can convert the Gerber files to GRBL G-code.
"""

from __future__ import annotations

from dataclasses import dataclass, replace
from heapq import heappop, heappush
from itertools import count
from math import hypot
from pathlib import Path
from typing import Iterable
from uuid import uuid5, NAMESPACE_URL


HERE = Path(__file__).resolve().parent
BOARD_NAME = "espnoise-cnc"
BOARD_WIDTH = 70.0
BOARD_HEIGHT = 24.5
USER_CENTERLINE_Y = BOARD_HEIGHT / 2
MIN_TRACK_WIDTH = 1.00
MIN_CLEARANCE = 0.40
POWER_TRACK_WIDTH = 1.30
# The physical blanks can be shorter than their nominal 70 mm length. Move
# all copper and holes toward the left edge. This gives more tolerance at the
# right edge, while the outline stays at the nominal unit size.
LAYOUT_SHIFT_X = -0.50

# Physical values from the user's prototype board. The microphone diameter is
# approximate. The acoustic hole is confirmed at the module center.
MIC_MODULE_DIAMETER = 13.0
MIC_PIN_PITCH_X = 2.54
MIC_ROW_PITCH_Y = 7.62
MIC_ACOUSTIC_OFFSET_X = 0.0
MIC_ACOUSTIC_OFFSET_Y = 0.0
BUZZER_BODY_DIAMETER = 12.0
BUZZER_LEAD_PITCH = 6.5
BUZZER_LEAD_DIAMETER = 0.5
BUZZER_DRILL_DIAMETER = 0.8


@dataclass(frozen=True)
class Pad:
    number: str
    x: float
    y: float
    net: str
    diameter: float = 2.0
    drill: float = 0.9
    side: str = "both"
    shape: str = "circle"
    width: float | None = None
    height: float | None = None

    @property
    def copper_radius(self) -> float:
        return max(self.width or self.diameter, self.height or self.diameter) / 2


@dataclass(frozen=True)
class Component:
    ref: str
    value: str
    face: str
    x: float
    y: float
    body_width: float
    body_height: float
    pads: tuple[Pad, ...]
    note: str = ""
    footprint: str = "ESPNoise:CNC_Custom"
    body_shape: str = "rect"


@dataclass(frozen=True)
class Track:
    net: str
    layer: str
    points: tuple[tuple[float, float], ...]
    width: float = MIN_TRACK_WIDTH


@dataclass(frozen=True)
class Via:
    x: float
    y: float
    net: str
    diameter: float = 1.7
    drill: float = 0.8


components: list[Component] = []
tracks: list[Track] = []
vias: list[Via] = []


def add_component(component: Component) -> None:
    components.append(component)


def add_track(
    net: str,
    layer: str,
    *points: tuple[float, float],
    width: float = MIN_TRACK_WIDTH,
) -> None:
    tracks.append(Track(net, layer, tuple(points), width))


def add_via(x: float, y: float, net: str) -> Via:
    item = Via(x, y, net)
    vias.append(item)
    return item


def th_pad(
    number: int | str,
    x: float,
    y: float,
    net: str,
    *,
    drill: float = 0.9,
    diameter: float | None = None,
) -> Pad:
    return Pad(str(number), x, y, net, diameter=diameter or max(1.6, drill + 0.6), drill=drill)


def smd_pad(
    number: int | str,
    x: float,
    y: float,
    net: str,
    width: float,
    height: float,
) -> Pad:
    return Pad(
        str(number), x, y, net, drill=0.0, side="F.Cu", shape="rect", width=width, height=height
    )


# User face: the two switches, microphone module, and buzzer only.
add_component(
    Component(
        "SW2",
        "BUZZER ENABLE (7-7 ZS)",
        "User",
        7.0,
        USER_CENTERLINE_Y,
        7.0,
        7.0,
        (
            th_pad(1, 5.0, 9.75, "", drill=1.0),
            th_pad(2, 7.0, 9.75, "", drill=1.0),
            th_pad(3, 9.0, 9.75, "", drill=1.0),
            th_pad(4, 5.0, 14.75, "+5V_BUZZER_SW", drill=1.0),
            th_pad(5, 7.0, 14.75, "+5V_PERIPH", drill=1.0),
            th_pad(6, 9.0, 14.75, "", drill=1.0),
        ),
        "Extended state enables buzzer power.",
        "ESPNoise:7x7_DPDT_Pushbutton",
    )
)
add_component(
    Component(
        "SW1",
        "MUTE (7-7 WS)",
        "User",
        18.0,
        USER_CENTERLINE_Y,
        7.0,
        7.0,
        (
            th_pad(1, 16.0, 9.75, "", drill=1.0),
            th_pad(2, 18.0, 9.75, "", drill=1.0),
            th_pad(3, 20.0, 9.75, "", drill=1.0),
            th_pad(4, 16.0, 14.75, "", drill=1.0),
            th_pad(5, 18.0, 14.75, "MUTE_N", drill=1.0),
            th_pad(6, 20.0, 14.75, "GND", drill=1.0),
        ),
        "Momentary mute button.",
        "ESPNoise:7x7_DPDT_Pushbutton",
    )
)

mic_center_x = 36.0 - MIC_ACOUSTIC_OFFSET_X
mic_center_y = USER_CENTERLINE_Y - MIC_ACOUSTIC_OFFSET_Y
mic_x = [mic_center_x - MIC_PIN_PITCH_X, mic_center_x, mic_center_x + MIC_PIN_PITCH_X]
mic_top_y = mic_center_y - MIC_ROW_PITCH_Y / 2
mic_bottom_y = mic_center_y + MIC_ROW_PITCH_Y / 2
add_component(
    Component(
        "MIC1",
        "MH-ET LIVE INMP441 2x3 MODULE",
        "User",
        mic_center_x,
        mic_center_y,
        MIC_MODULE_DIAMETER,
        MIC_MODULE_DIAMETER,
        (
            th_pad(1, mic_x[0], mic_top_y, "GND", drill=1.0, diameter=2.0),
            th_pad(2, mic_x[1], mic_top_y, "+3V3", drill=1.0, diameter=2.0),
            th_pad(3, mic_x[2], mic_top_y, "MIC_SD", drill=1.0, diameter=2.0),
            th_pad(4, mic_x[0], mic_bottom_y, "GND", drill=1.0, diameter=2.0),
            th_pad(5, mic_x[1], mic_bottom_y, "MIC_WS", drill=1.0, diameter=2.0),
            th_pad(6, mic_x[2], mic_bottom_y, "MIC_SCK", drill=1.0, diameter=2.0),
        ),
        "The printed-label and acoustic-hole face points toward the case top. In that face view, with the notch at the local top edge: top row 1 GND, 2 VDD, 3 SD; bottom row 4 L/R, 5 WS, 6 SCK. L/R is grounded. The pin pitches and centered acoustic hole are confirmed. The 13 mm body is approximate.",
        "ESPNoise:MH_ET_LIVE_INMP441_2x3_P2.54_Row7.62",
        "circle",
    )
)
add_component(
    Component(
        "BZ1",
        "TWO-PIN 5 V BUZZER",
        "User",
        61.0,
        USER_CENTERLINE_Y,
        BUZZER_BODY_DIAMETER,
        BUZZER_BODY_DIAMETER,
        (
            th_pad(1, 61.0 + BUZZER_LEAD_PITCH / 2, USER_CENTERLINE_Y, "+5V_BUZZER_SW", drill=BUZZER_DRILL_DIAMETER, diameter=2.0),
            th_pad(2, 61.0 - BUZZER_LEAD_PITCH / 2, USER_CENTERLINE_Y, "BUZZER_COLLECTOR", drill=BUZZER_DRILL_DIAMETER, diameter=2.0),
        ),
        "Passive buzzer with top sound port. Pad 1 is + and pad 2 is -. The measured body is 12 mm, the lead pitch is 6.5 mm, and each lead is 0.5 mm. D1 protects the driver from the coil turn-off pulse.",
        "ESPNoise:Buzzer_THT_2Pin_P6.50mm_D12mm",
        "circle",
    )
)
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

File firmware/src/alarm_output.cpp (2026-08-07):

#include "alarm_output.h"

#include <Adafruit_NeoPixel.h>

#include <cmath>
#include <cstdint>

#include "board_profile.h"
#include "config.h"

#ifndef ESPNOISE_LED_STARTUP_TEST
#define ESPNOISE_LED_STARTUP_TEST 0
#endif

#ifndef ESPNOISE_BUZZER_STARTUP_TEST
#define ESPNOISE_BUZZER_STARTUP_TEST 0
#endif

#ifndef ESPNOISE_BUZZER_MELODY_TEST
#define ESPNOISE_BUZZER_MELODY_TEST 0
#endif

#ifndef ESPNOISE_PRODUCTION_STARTUP_CHECK
#define ESPNOISE_PRODUCTION_STARTUP_CHECK 0
#endif

namespace alarm_output {
namespace {

constexpr uint8_t kBuzzerPwmChannel = 0;

Adafruit_NeoPixel pixels(config::kLedCount, board_profile::kLedDataPin,
                         NEO_GRBW + NEO_KHZ800);

bool peripheralPowerOn = false;
uint32_t displayedColor = UINT32_MAX;
uint32_t currentBuzzerFrequencyHz = 0;
RuntimeSettings runtimeSettings;
bool bluetoothTransitionActive = false;
bool bluetoothTransitionEnables = false;
uint32_t bluetoothTransitionStartMs = 0;

uint8_t buzzerDutyForVolume() {
  const uint8_t volume = runtimeSettings.buzzerVolumePercent;
  if (volume == 0) {
    return 0;
  }

  // A passive piezo responds to the fundamental part of the PWM waveform.
  // Map the requested electrical tone amplitude to the short PWM pulse that
  // produces it. A 100% setting gives the maximum 50% PWM duty.
  constexpr float kPi = 3.14159265F;
  const float amplitude = static_cast<float>(volume) / 100.0F;
  const float duty = asinf(amplitude) / kPi;
  return static_cast<uint8_t>(lroundf(duty * 255.0F));
}

void setBuzzer(bool on) {
  ledcWrite(kBuzzerPwmChannel, on ? buzzerDutyForVolume() : 0);
}

void setBuzzerFrequency(uint32_t frequencyHz) {
  if (frequencyHz == currentBuzzerFrequencyHz) {
    return;
  }
  setBuzzer(false);
  ledcSetup(kBuzzerPwmChannel, frequencyHz, 8);
  currentBuzzerFrequencyHz = frequencyHz;
}
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

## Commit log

2026-08-03 Add production 3D print release
    [back.stl, button.stl, case.stl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]
2026-08-03 Fix accessory pairing and add setting sliders
    [ble_service.cpp]
2026-08-03 Add live positive noise measurements
    [ble_service.cpp, main.cpp]
2026-08-03 Add order-ready ESPNoise carrier PCB
    [espnoise-carrier-B_Cu.gbl, espnoise-carrier-B_Mask.gbs, espnoise-carrier-B_Paste.gbp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]
2026-08-03 Sync device names and reset global values
    [ble_service.cpp, main.cpp]
2026-08-03 Save device names when leaving the page
2026-08-03 Redesign carrier PCB for the 80 mm case
    [espnoise-carrier-B_Cu.gbl, espnoise-carrier-B_Mask.gbs, espnoise-carrier-B_Paste.gbp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]
2026-08-03 Move add device below the device list
2026-08-04 Fix alarm trigger and automatic settings sync
    [config.h, main.cpp, runtime_settings.h]
2026-08-04 Restore global live device charts
2026-08-04 Add fleet noise analytics
    [ble_service.cpp, main.cpp, noise_analytics.h]
2026-08-05 Fix analytics sync and add UTC records
    [ble_service.cpp, main.cpp, noise_analytics.h]
2026-08-07 Prevent Bluetooth toggle restarts
    [alarm_output.cpp, ble_service.cpp, main.cpp]
2026-08-22 Add Cubiko CNC PCB workflow
    [coupon-drills.csv, espnoise-cnc-bom.csv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]
2026-08-22 Fit two lean CNC PCBs on one panel
    [espnoise-cnc-bom.csv, espnoise-cnc-drills.csv, espnoise-cnc-netlist.csv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]
2026-08-22 Update the shared electronics tool pin
2026-08-22 Use the shared ESP32 library
2026-08-22 Correct CNC microphone and buzzer footprints
    [espnoise-cnc-bom.csv, espnoise-cnc-drills.csv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]
2026-08-22 Apply measured CNC part dimensions
    [espnoise-cnc-bom.csv, espnoise-cnc-drills.csv, espnoise-cnc.kicad_pcb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]
2026-08-22 Confirm centered microphone orientation
    [espnoise-cnc-bom.csv]
2026-08-22 fix(cnc): deepen PCB isolation pass
2026-08-22 feat(cnc): widen PCB tracks and user pads
    [espnoise-cnc-drills.csv, espnoise-cnc.kicad_pcb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]
2026-08-23 feat(cnc): widen tracks and isolation clearance
    [espnoise-cnc-drills.csv, espnoise-cnc.kicad_pcb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]
2026-08-23 Revise CNC files for manual unit rotation
    [espnoise-cnc-drills.csv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]
